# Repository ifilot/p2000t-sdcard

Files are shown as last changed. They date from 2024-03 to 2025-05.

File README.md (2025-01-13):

# P2000T SD-CARD cartridge







## Table of contents

* [Purpose](#purpose)
* [Downloads](#downloads)
* [How it functions](#how-it-functions)
* [Images](#images)
* [Commands](#commands)
* [Compilation instructions](#compilation-instructions)
* [Repository contents](#repository-contents)
* [Building the hardware](#building-the-hardware)
* [Ordering a cartridge](#ordering-a-cartridge)
* [Internal SD-card board](#internal-sd-card-board)
* [Formatting SD-card](#formatting-sd-card)
* [License](#license)

> [!TIP] 
> Have questions or comments about the **P2000T SD-card cartridge**? Join
> the conversation and chat with the developers on our [Discord
> server](https://discord.gg/YtzJTWYAxy).

## YouTube

Check out the YouTube video below for a detailed review of the SD-card cartridge.

YouTube (https://www.youtube.com/watch?v=OKvVlIvrEu0)

## Purpose

Perhaps the most elegant solution for loading CAS files into your P2000T or
making backups of your tapes is via a cartridge that hosts an SD-card slot. Even
the smallest SD-cards have enough capacity to store the complete P2000T tape
archive. Reading from such an SD-card is non-trivial and requires both a
hardware solution to interface with the I/O port of the P2000T as well as a
software solution to navigate through the files hosted on a FAT32 partition.
This repository contains the PCB for interfacing a P2000T with an SD-card and
the necessary software routines to grab .CAS files from said SD card and load
them into memory.

> [!TIP]
> **Documentation**
> * Detailed documentation included how-to procedures can be found [here](https://www.philips-p2000t.nl/cartridges/sdcard-cartridge.html#sdcard-cartridge)
> * There is also a [manual in Dutch](https://github.com/ifilot/P2000T-SD-kaart-handleiding) Dutch flag available.

## Downloads 

Read the section ["How it functions"](#how-it-functions) to understand what each
download file does.

> [!WARNING] 
> The files shown here cater specifically to PCB version 6 or later
> where the SD-card listens to I/O port 0x4X. Earlier version of the PCB are no
> longer actively maintained.

* [BASICBOOTSTRAP.BIN](https://github.com/ifilot/p2000t-sdcard/releases/latest/download/BASICBOOTSTRAP.BIN)
* [FLASHER.BIN](https://github.com/ifilot/p2000t-sdcard/releases/latest/download/FLASHER.BIN)
* [LAUNCHER.BIN](https://github.com/ifilot/p2000t-sdcard/releases/latest/download/LAUNCHER.BIN)

> [!TIP]
> * Precompiled SD-card images, including flashing instructions, can be found [here](https://github.com/ifilot/p2000t-sdcard-image)
> * A list of PRG programs, specifically designed to operate with the SD-card cartridge, can be found [here](https://github.com/ifilot/p2000t-sdcard-cartridge-programs)

## How it functions

To interface with the SD-card, an SD-card slot is connected to the I/O port of
the P2000T. Interfacing with the SD-card proceeds via the SPI protocol which is
encoded in hardware (in contrast to bit-banging the protocol in software). From
the perspective of the P2000T, simple 1-byte instructions can be sent and
retrieved from the SD-card. By sending specific commands, data is sent or
retrieved from the SD-card.

While the SLOT2 cartridge (which hooks up to the I/O port of the P2000T) hosts
the circuitry to interface with the SD-card, a SLOT1 cartridge is required that
hosts the software. In order to run BASIC programs that are stored on the
SD-card as `.CAS` files, the regular BASIC environment **and** the required
routines to interface with the SD-card need to be present in memory. For this
reason, a modified version of the BASIC environment is used which upon boot will
load a launcher application from the ROM chip on the SLOT2 cartridge into main
memory. This launcher application allows the user to navigate the SD-card and
load BASIC programs into memory and run these. Detailed instructions on this
process are found [here](https://www.philips-p2000t.nl/cartridges/sdcard-cartridge.html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).

The launcher application needs to be placed on the ROM chip by means of a
flasher program. The flasher program is a different SLOT1 cartridge which can be
downloaded from the [download section](#downloads). The flasher program will
copy a `LAUNCHER.BIN` file from the root folder of the SD-card to the ROM chip
on the SLOT2 cartridge. This procedure is also used to update the launcher
application. Details on this process can be found [here](https://www.philips-p2000t.nl/cartridges/sdcard-cartridge.html#flashing-the-launcher-onto-the-rom-chip).

It is also possible to make copies of existing tapes to the SD-card. For this
purpose, a `CASDUMP.PRG` program is written. These special types of programs can
be loaded from the SD-card and executes via the launcher application. After
completion, one automatically returns to the launcher, allowing one to load one
of the freshly copied programs.

## Images

SLOT2 cartridge enclosure and populated PCB.
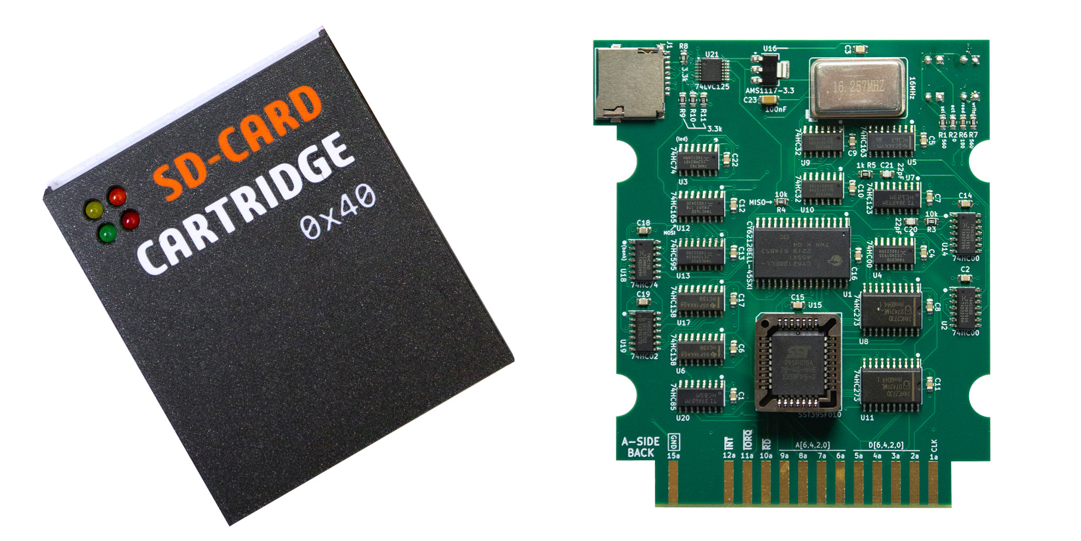
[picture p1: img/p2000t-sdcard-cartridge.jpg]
Image of cartridge and PCB


Screenshots of navigation and execution of .CAS files.
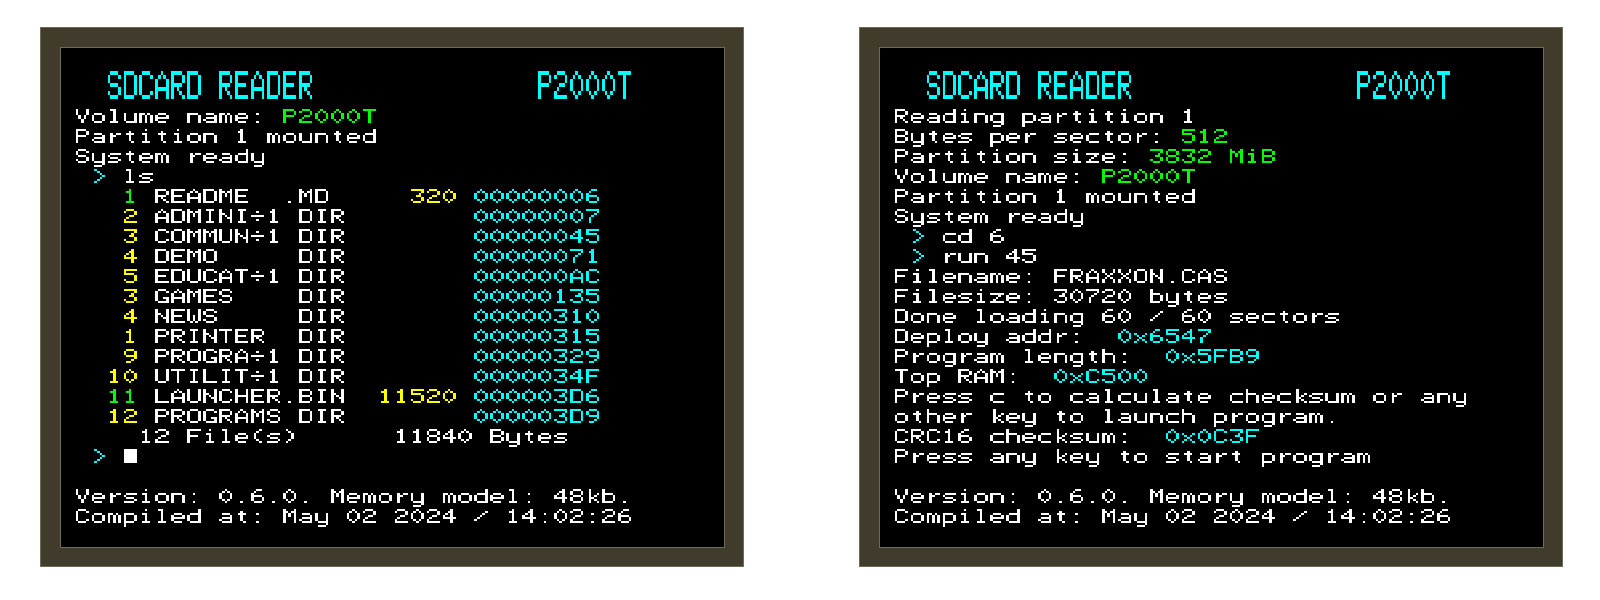
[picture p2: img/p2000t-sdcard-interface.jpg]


## Commands

Upon booting into the LAUNCHER application, the user interfaces with the SD-card
using a set of short commands. Below, the list of commands is provided

| **Command** | **Description** |
| --- | ---|
| `ls` | List contents of current folder |
| `lscas` | List contents of current folder, listing contents of CAS files |
| `cd <number>` | Change directory |
| `run <number>` | Run .CAS file |
| `hexdump <number>`  | Performs a 120-byte hexdump of a file |
| `fileinfo <number>` | Provides location details of a file |
| `ledtest` | Performs a quick test on the read/write LEDs |
| `stack` | Show current position of the stack pointer |
| `dump<XXXX>` | Perform a 120-byte hexdump of main memory starting at `0xXXXX` |
| `romdump<XXXX>` | Perform a 120-byte hexdump of cartridge ROM starting at `0xXXXX`  |
| `ramdump<XXXX>` | Perform a 120-byte hexdump of cartridge RAM starting at `0xXXXX`  |

Note that `<number>` needs to replaced with the specific number of a file. Users
who are familiar with command line interfaces are probably used to specifying
filenames rather than numbers. This reason this approach was chosen is mainly
because it is simpler to program and furthermore a bit quicker to type.

## Compilation instructions

Compilation is done using the [z88dk Docker](https://hub.docker.com/r/z88dk/z88dk)
by means of `compile.sh`. To compile the launcher, run

```bash
cd src
./compile launcher
```

and for the flasher utility

```bash
cd src
./compile flasher
```

## Repository contents

* [Cartridge cases](cases/)
* [PCB layout files (KiCAD)](pcb/port2-sdcard-interface/)
* [Modified BASIC ROM source files](basicmod/)
* [Launcher and Flasher programs](src/)
* [Custom programs](programs/)

## Building the hardware

### Gerber files

To create your own SLOT2 cartridge, download the GERBER files from
[here](pcb/port2-sdcard-interface/GERBERS/), put them in a `.ZIP` file and send
them to your favorite PCB print farm. The author of this repository mainly uses
[JLCPCB](https://jlcpcb.com/), but plenty of alternatives are available. The
SLOT2 PCB has four layers. It is recommended to apply an ENIG (gold) coating and
chamfer the edge connector for facile insertion into the P2000T. After ordering,
one needs to either hand-solder the components (which can be tricky for the SMD
chips) or alternatively make use of an assembly service by which the PCB print
farm will solder these components for you.

### PCB assembly service

The folder [pcb/port2-sdcard-interface](pcb/port2-sdcard-interface) contains
`port2-sdcard-interface_bom_bot.csv` and `port2-sdcard-interface-bottom-pos.csv`
which can be used for the JLCPCB assembly service. An example of the part
placement can be found in the image below. At the time of writing, two
components were unavailable, being the memory chip `62128` and a 0 ohm resistor,
which is the reason that these two parts are missing. Note that all through-hole
parts, e.g. LEDs, oscillator and PLCC32 socket, have to be hand-soldered in.

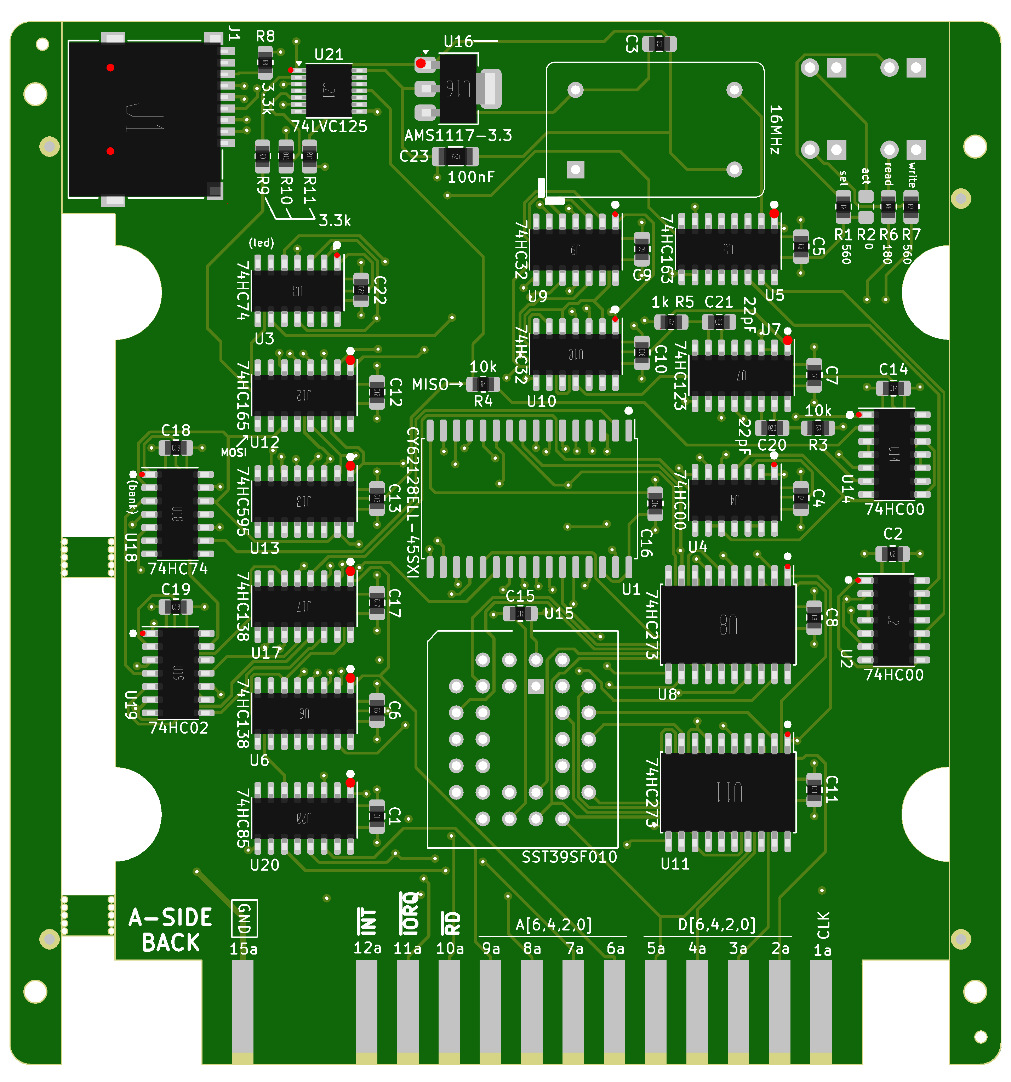
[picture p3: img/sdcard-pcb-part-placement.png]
img PCB assembly


### Ordering a cartridge

It is also possible to order a cartridge (typically there are always a few
of them in stock). If you are interested, feel free to contact the author of
this repository at `ivo at ivofilot dot nl` to discuss pricing and shipping.

## Internal SD-card board

This project also includes an [internal SD-card
board](pcb/internal-sdcard-interface/) designed to mount on top of the main
baseboard inside the P2000T. In addition to the SD-card reader functionality,
the board also provides 64 KiB of additional memory, making it an all-in-one
solution.

To install this board, you will need two custom brackets. You can find the
necessary bracket files [here](brackets).

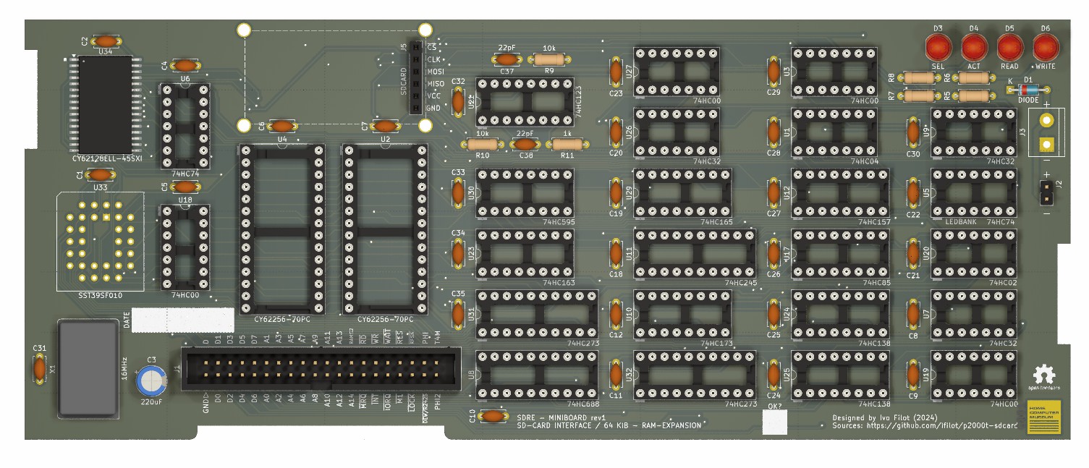
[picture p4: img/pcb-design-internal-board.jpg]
internal SD-card board


## Formatting SD-card

The way that the SD-card is formatted is critical. The SD-card needs be
formatted using a MBR/FAT32 partition. Often, directly formatting the SD-card
via Windows Explorer or similar works well, but sometimes a more rigorous
procedure is needed, which is explained below.

1. Type `WINDOWS + R` and run `CMD`.
2. Run `diskpart`.
3. Type `list disk` followed by `select disk <NR>` where `<NR>` corresponds to
   your SD-card.
4. Type `clean`. You get a response with `DiskPart succeeded in cleaning the
   disk.`.
5. Type `list volume`, followed by `select volume <ID>` where `<ID>` corresponds
   to your SD-card drive.
6. Type `convert mbr`. You should get the response `DiskPart successfully
   converted the selected disk to MBR format.`.
7. Type `create partition primary`. The response should be `DiskPart succeeded
   in creating the specified partition.`.
8. Finally, type `format fs=fat32 quick label="P2000T"`, after which the
   response is `DiskPart successfully formatted the volume.`.

Your SD-card should now be ready to work in the SD-cartridge. Of course, you
still need to copy files to it in order to load something of it.

## License

License facts

* All software is shared under the [GPL v3 license](https://www.gnu.org/licenses/gpl-3.0).
* All hardware (e.g. KiCAD files and .stl files) are shared under the [CERN-OHL-S license](https://ohwr.org/project/cernohl/-/wikis/uploads/819d71bea3458f71fba6cf4fb0f2de6b/cern_ohl_s_v2.txt).
* All documentation is shared under the [CC-BY-SA 4.0 license](https://creativecommons.org/licenses/by-sa/4.0/).

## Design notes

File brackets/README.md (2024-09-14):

# P2000T Mounting Brackets

This folder contains the STL files for two mounting brackets (see image below)
for installing the hybrid SD-card / memory expansion internal board.

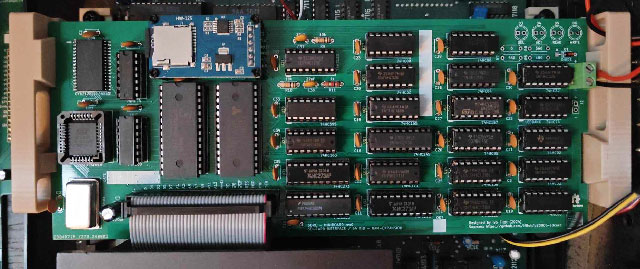
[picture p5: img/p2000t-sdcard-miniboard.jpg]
brackets on SD-card miniboard


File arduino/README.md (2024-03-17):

# Arduino SD-card interface

This folder contains a set of Arduino scripts to interface with an SD-card. These
scripts were used for prototyping the SD-card interface and are left here for
development purposes. These scripts are not used for the P2000T SD-card
cartridge.

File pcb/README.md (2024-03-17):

# PCB

This folder contains the PCBs for the [SLOT2 SD-card cartridge](port2-sdcard-interface) 
and also for a [SD-card interface prototype PCB](sdcard-prototype). 
The latter is only used for development purposes and can be ignored if one is 
solely interested in building a SLOT2 cartridge.

## Bill of materials

* 1 x CY62128ELL-45SXI
* 3 x 74HC00
* 2 x 74HC74
* 1 x 74HC163
* 2 x 74HC138
* 1 x 74HC123
* 2 x 74HC273
* 2 x 74HC32
* 1 x HC165
* 1 x HC595
* 1 x SST39SF010
* 1 x 74HC02
* 1 x 74HC85
* 1 x 16MHz crystal oscillator

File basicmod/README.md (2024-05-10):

# DEMO - IOLOADER

This example shows how via a small piece of injected code, another
piece of code can be loaded from the I/O port.

## Mechanism

To insert the custom code in the system RAM, two hijacks are made. The first
one is done in the startup procedure. Normally, at 0x1F71, a call is made to 
address 0x1056 which contains a jump to address 0x1F5A. This call is hijacked 
by changing the address pointer at 0x1057-0x1058 to 0x4EE0, which is an empty 
part of the BASIC rom. At this point, custom code is inserted which at its
end makes the required jump to 0x1F5A, from which the initiation procedure 
continues.

The small piece of code that is inserted at 0x4EE0 stores the value 0x55
at memory address 0x6150 (which is free to use). When this value is present,
another hijacked memory routine is activated. This routine is rather small
and resides at 0x4CE7. Here, a check is made whether memory address 0x6150
contains the value 0x55 and if so, a jump is made to 0x6151 where the bootloader
can place a custom pointer to any desired piece of code to be executed. When
desired, this custom piece of code can always return with a `jp 0029h` to
return to the BASIC execution (assuming no drastic changes are made to the
BASIC infrastructure).

## Output

* `BASICBOOTSTRAP.bin`: Modified BASIC cartridge

## Compilation instructions

Prepare the Docker compiler image

```bash
docker build . -t basicmod-compiler
```

Use the Docker image for the compilation

```bash
./compile
```

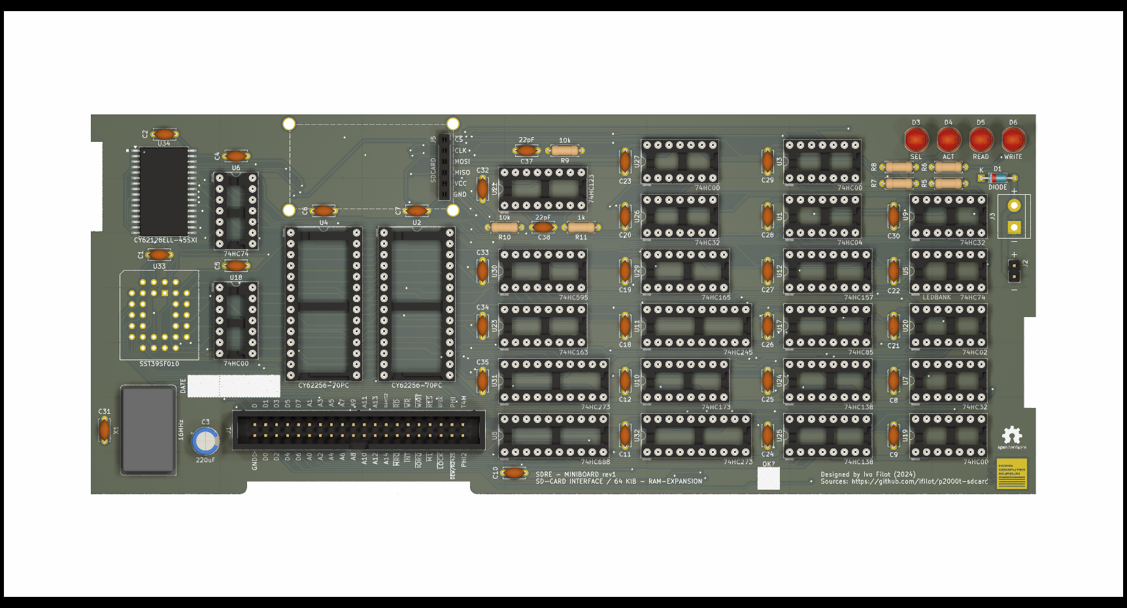
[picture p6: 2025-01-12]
img/pcb-design-internal-board.png

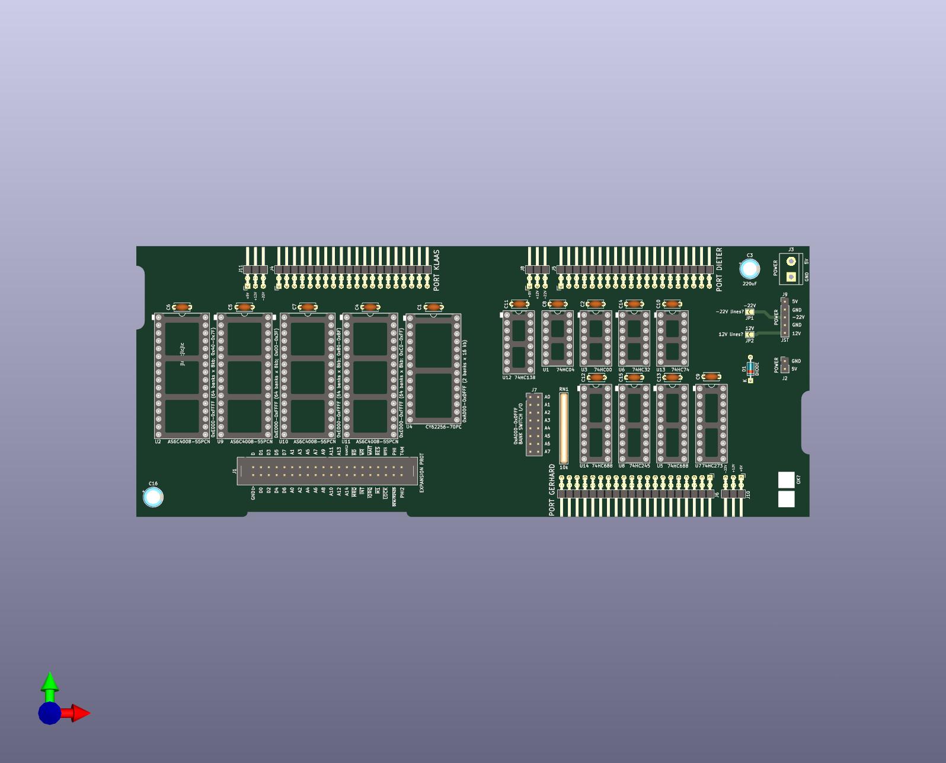
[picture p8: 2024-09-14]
pcb/internal-sdcard-interface/internal-sdcard-interface.jpg

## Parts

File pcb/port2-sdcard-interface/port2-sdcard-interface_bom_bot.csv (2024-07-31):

Designator | Comment | Footprint | LCSC Part #
U21 | 74LVC125 | Package_SO:TSSOP-14_4.4x5mm_P0.65mm | C6059
U16 | AMS1117-3.3 | Package_TO_SOT_SMD:SOT-223-3_TabPin2 | C5346136
R3,R4 | 10k | Resistor_SMD:R_0805_2012Metric_Pad1.20x1.40mm_HandSolder | C5159708
R5 | 1k | Resistor_SMD:R_0805_2012Metric_Pad1.20x1.40mm_HandSolder | C5123594
U1 | CY62128ELL-45SXI | Package_SO:SSOP-32_11.305x20.495mm_P1.27mm | C2840304
U2,U4,U14 | 74HC00 | Package_SO:SO-14_3.9x8.65mm_P1.27mm | C699445
C20,C21 | 22pF | Capacitor_SMD:C_0805_2012Metric_Pad1.18x1.45mm_HandSolder | C525286
R2 | 0 | Resistor_SMD:R_0805_2012Metric_Pad1.20x1.40mm_HandSolder | C431818
R6 | 180 | Resistor_SMD:R_0805_2012Metric_Pad1.20x1.40mm_HandSolder | C25270
R1,R7 | 560 | Resistor_SMD:R_0805_2012Metric_Pad1.20x1.40mm_HandSolder | C429158
R8,R9,R10,R11 | 3.3k | Resistor_SMD:R_0805_2012Metric_Pad1.20x1.40mm_HandSolder | C407459
J1 | Micro_SD_Card_Det1 | components:CONN9_MSD-1_CUD | C381082
U5 | 74HC163 | Package_SO:SOIC-16_3.9x9.9mm_P1.27mm | C338758
C23 | 100nF | Capacitor_SMD:C_1206_3216Metric_Pad1.33x1.80mm_HandSolder | C309030
U8,U11 | 74HC273 | Package_SO:SOIC-20W_7.5x12.8mm_P1.27mm | C131486
C1,C2,C3,C4,C5,C6,C7,C8,C9,C10,C11,C12,C13,C14,C15,C16,C17,C18,C19,C22 | 0.1uF | Capacitor_SMD:C_0805_2012Metric_Pad1.18x1.45mm_HandSolder | C126469
U3,U18 | 74HC74 | Package_SO:SO-14_3.9x8.65mm_P1.27mm | C27597
U20 | 74HC85 | Package_SO:SOIC-16_3.9x9.9mm_P1.27mm | C5953
U13 | 74HC595 | Package_SO:SOIC-16_3.9x9.9mm_P1.27mm | C5947
U9,U10 | 74HC32 | Package_SO:SO-14_3.9x8.65mm_P1.27mm | C5632
U12 | 74HC165 | Package_SO:SOIC-16_3.9x9.9mm_P1.27mm | C5613
U6,U17 | 74HC138 | Package_SO:SOIC-16_3.9x9.9mm_P1.27mm | C5602
U7 | 74HC123 | Package_SO:SOIC-16_3.9x9.9mm_P1.27mm | C5597
U19 | 74HC02 | Package_SO:SO-14_3.9x8.65mm_P1.27mm | C5588

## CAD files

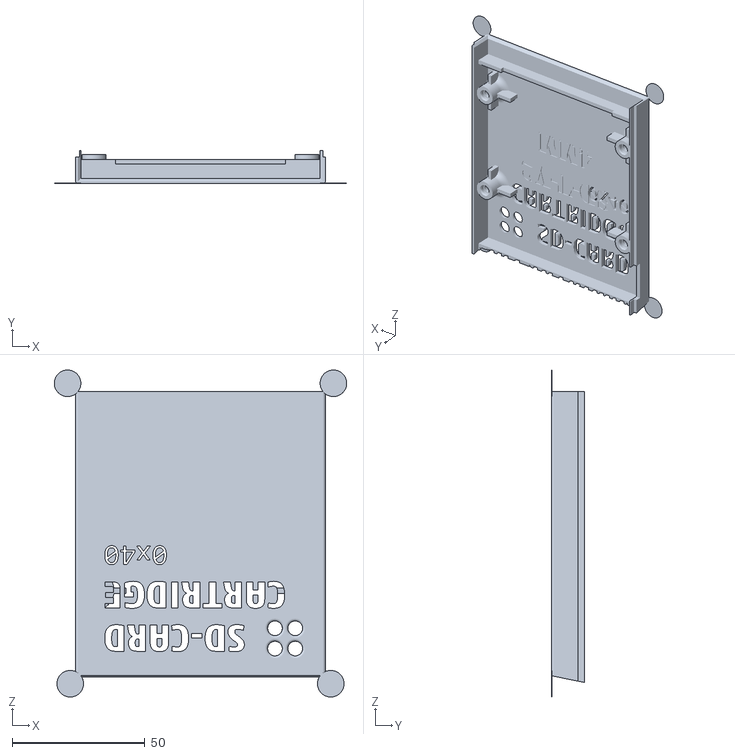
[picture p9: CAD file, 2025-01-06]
cases/multicolor/p2000t-sdcard-top-main.stl
110.0 x 12.5 x 123.0

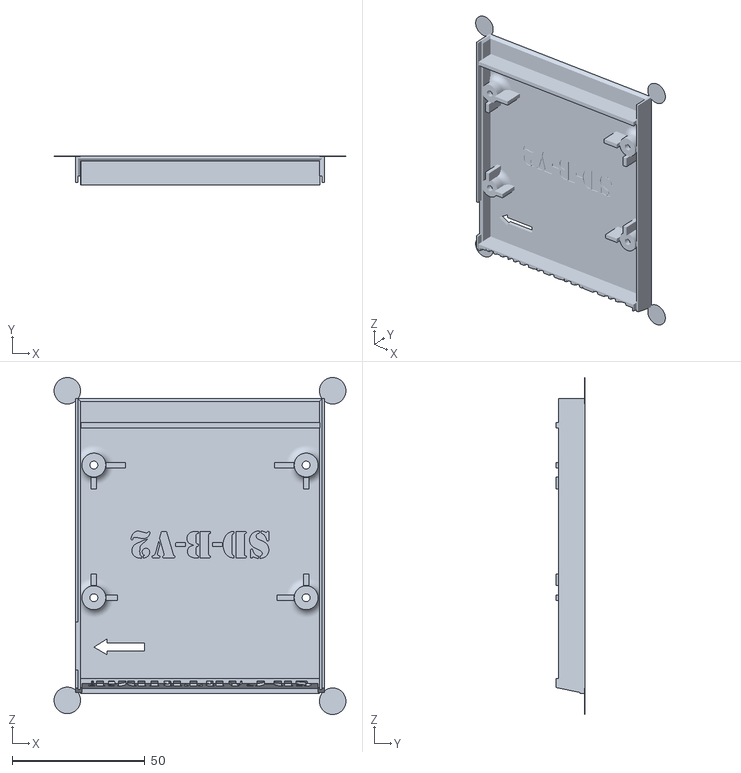
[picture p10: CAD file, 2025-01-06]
cases/multicolor/p2000t-sdcard-bottom-main.stl
110.0 x 11.0 x 127.0

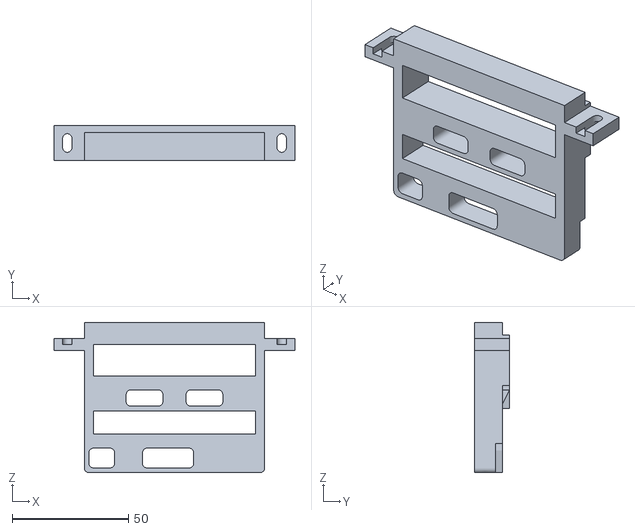
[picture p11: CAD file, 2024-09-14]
brackets/p2000t_SDRE_mounting_bracket_left.stl
103.5 x 15.0 x 64.5

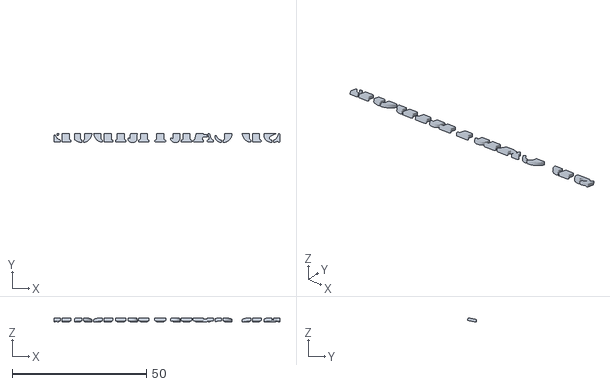
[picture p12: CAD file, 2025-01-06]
cases/multicolor/p2000t-sdcard-top-namelabel.stl
84.1 x 3.40 x 1.67

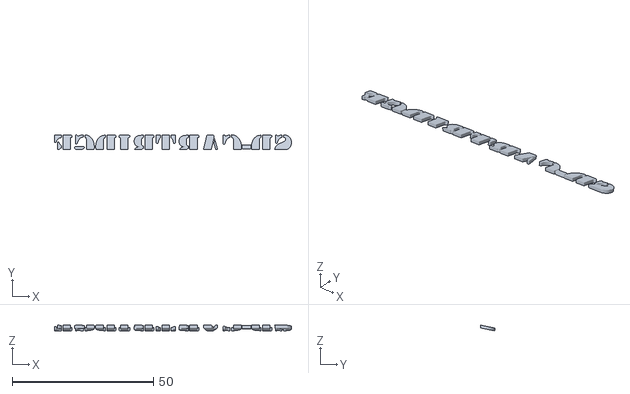
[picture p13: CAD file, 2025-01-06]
cases/multicolor/p2000t-sdcard-bottom-namelabel.stl
84.0 x 5.15 x 2.03

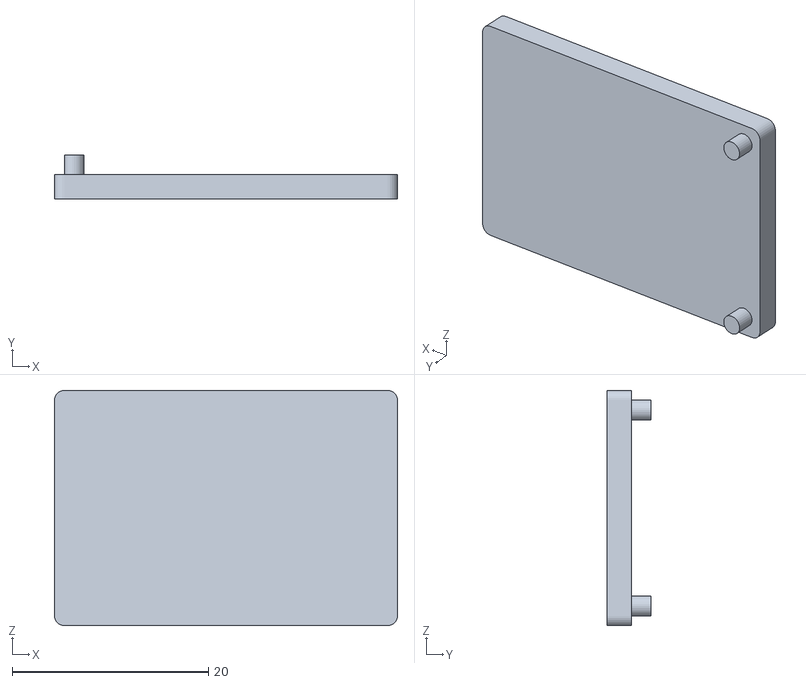
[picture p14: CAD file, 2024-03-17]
cases/single/sdcard-fixator-plate.stl
35.0 x 4.50 x 24.0

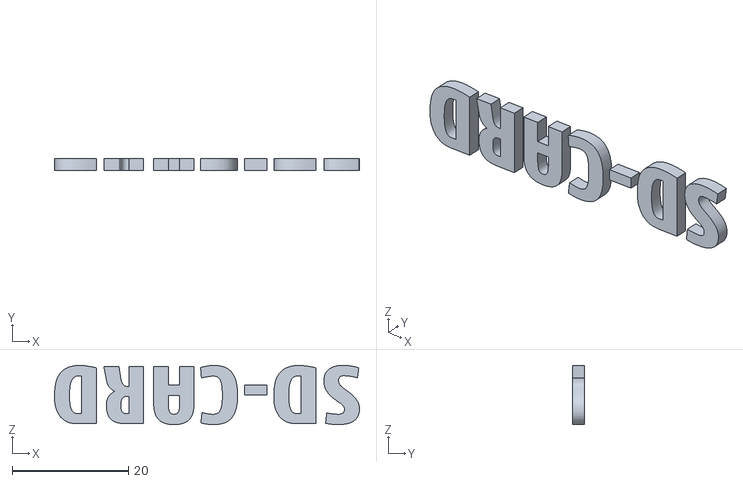
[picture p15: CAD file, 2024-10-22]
cases/multicolor/p2000t-sdcard-top-label01.stl
52.5 x 2.00 x 10.2

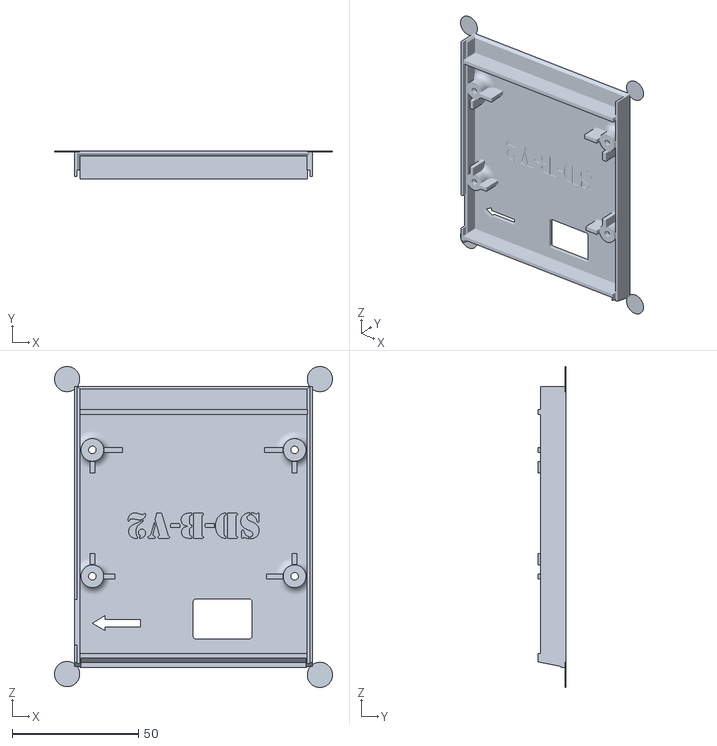
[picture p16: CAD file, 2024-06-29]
cases/multicolor/p2000t_multicartridge-bottom-osscillator-hole.stl
110.0 x 11.0 x 127.0

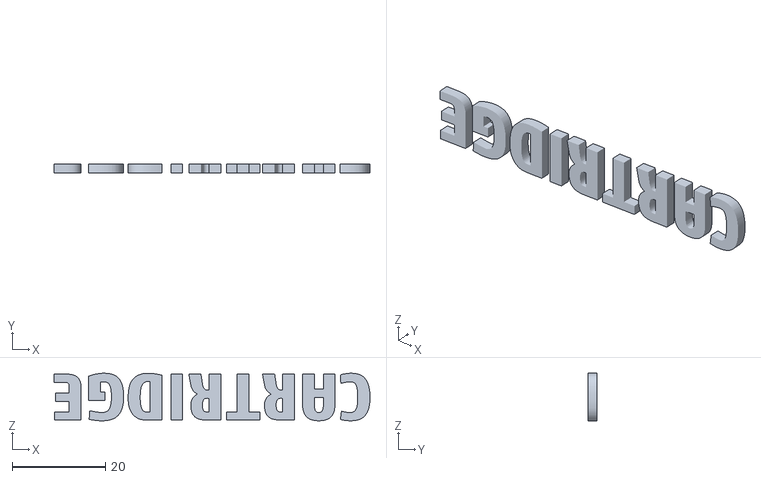
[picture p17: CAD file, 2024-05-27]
cases/multicolor/p2000t-sdcard-top-label02.stl
67.7 x 2.00 x 10.2

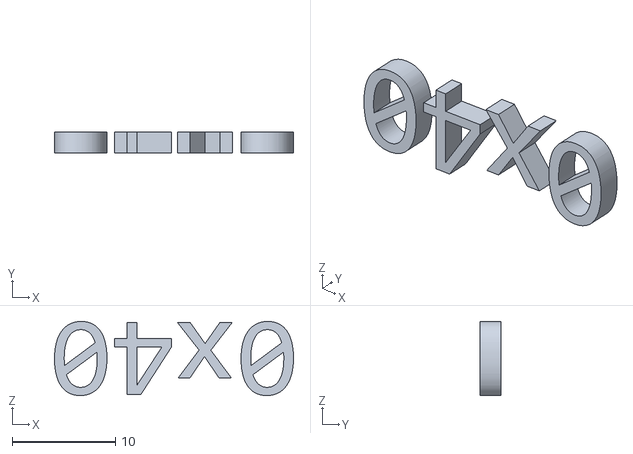
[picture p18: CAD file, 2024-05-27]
cases/multicolor/p2000t-sdcard-top-0x40-label.stl
23.2 x 2.00 x 7.19

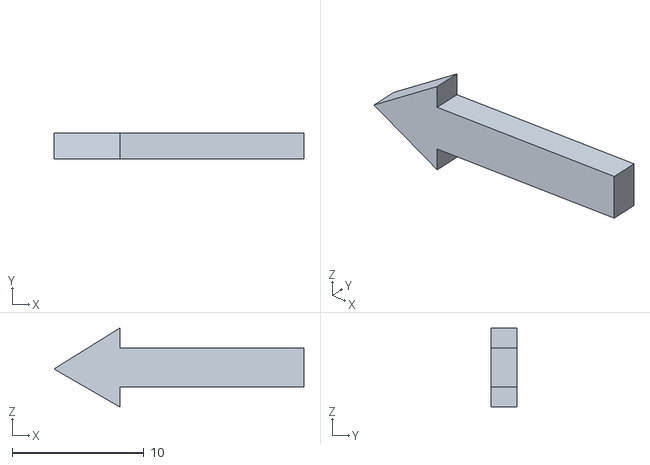
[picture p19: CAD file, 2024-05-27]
cases/multicolor/p2000t-sdcard-bottom-arrow.stl
19.0 x 2.00 x 6.00

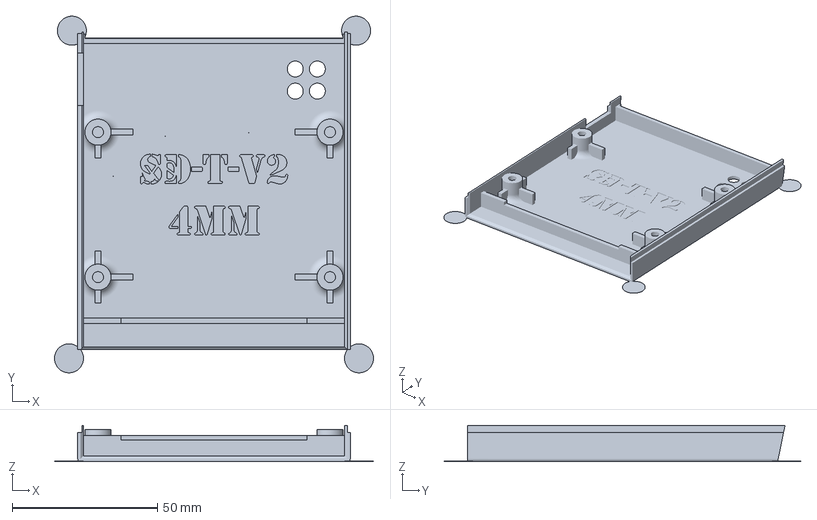
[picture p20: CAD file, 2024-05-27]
cases/multicolor/p2000t-sdcard-top.3mf
110.0 x 123.0 x 12.5 mm

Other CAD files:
cases/single/p2000t-sdcard-bottom.stl
brackets/p2000t_SDRE_mounting_bracket_right.stl
cases/single/p2000t-sdcard-top_4mm_inserts.stl
cases/single/p2000t-sdcard-top.stl
cases/multicolor/p2000t-sdcard-bottom.3mf

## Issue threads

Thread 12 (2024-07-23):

Good work and a little idea

emilen72, 2024-07-23:
Can you think to be possible to port this projet to use the pi pico rp2040, the purple clone with 16MB on board and make a multicart or a .cas loader from it? it would be very cheap :-) and easy to build (the hardware assembly of course)

it's already been done for atari 800 and othe console... some links that maybe you know...
https://forums.atariage.com/topic/351546-a8picocart-unocart-on-a-raspberry-pi-pico/
https://github.com/robinhedwards/A8PicoCart
https://github.com/aotta/PiCOLECO
https://github.com/aotta/SD-1000
https://github.com/aotta/PiRTOII

only a little idea :-)

best regards
Emiliano

ifilot, 2024-07-23:
This is indeed a nice suggestion and I have been pondering about this myself in the past. Two things held me back, the Raspberry Pi PICO has fewer pins than I would like and these pins operate at 3.3V, not 5.0V. Now there are a number of posts out there that suggest that the PICO is 5.0V tolerant with exception of the ADC pins, but so far I have not dared to put that to the test. All my projects involving the PICO use level-shifting.

I reckon porting this project to the PICO is certainly possible, essentially encoding what I have now put in hardware into software. It is something I might do in the future, but right now I have already enough projects on my hands and I would rather complete the ones I have now than starting new ones.

I do appreciate the list of links you have provided. If (when) I am going to adopt this endeavor, this will nicely kick-start the project.

Closed 2024-07-30.

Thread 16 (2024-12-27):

Ensure copper fill does not overlap with edge connector.

ifilot, 2024-12-27:
The manufacturing service observed that the copper fill around the edge connector sometimes results in exposed copper after the 30 deg chamfering step. Although most likely harmless, it is better to avoid this altogether.

Closed 2025-01-02.

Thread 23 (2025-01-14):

Sort filenames

ifilot, 2025-01-14:
In the current implementation, the files and directories are listed in the same order they are stored in that FAT32 system. Ideally, first directories are listed followed by files. With this functionality in place, it might also become possible to use commands like `run <filename>` rather than `run <number>`, but this is something we have to carefully evaluate as using the number-based system is a bit more efficient in terms of typing.

dionoid, 2025-06-06:
Sorting a long list of filenames will hurt the performance of the SD-cart cartridge, as all the files within a specific FAT32 folder need to be read and then sorted using the "power" of the old Z80 chip.

There are PC tools like [DriveSort](https://www.anerty.net/software/file/DriveSort/) (for Windows) and [FATSort](https://fatsort.sourceforge.io/) (for Linux/Mac) which both can sort FAT32 drives and allow you to choose if you want sort directories before files, or the other way around.

ifilot, 2025-06-07:
I can only agree with this. To provide some perspective: I have now implemented a FAT32 file sort routine for a 16 MHz 6502. There it is already noticeable suggesting that on a poor Z80 running at 2.5 MHz with much lower cycle efficiency, this will have a large negative impact. This will be a non-fix.

Closed 2025-06-07.

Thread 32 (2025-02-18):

viewing/running other files from a .cas file

fhil, 2025-02-18:
At the moment the 'lscas' command only shows the first file within a '.cas' file?
It would be really nice if 'lscas <num>' could be used to show all files within a '.cas' file.
And then use 'run <num>' to start an individual file.

I was trying to start the main program from the ancalagon.cas file. But that file is not the first file...

ifilot, 2025-02-18:
Thank you for raising this issue. Indeed, the firmware of the SD cartridge only lists the first "block" or "file" and the `run` command only starts the first file. If a CAS file contains multiple programs, only the first program or file can be accessed.

I need to align this with @dionoid how we wish to tackle this. I see a couple of options:
1. We instate the assumption that one CAS file should only contain one P2000T file. No multiple. CAS files that contain multiple P2000T files should then be broken up into separate ones. There is already software to do this.
2. We add a feature that allows the user to start the CAS file from any block (file) of interest. @dionoid has implemented a functionality to load a CAS file into memory and proceed to the BASIC prompt, but I am unsure whether this functionality allows one to load a file "in the middle" of a CAS file.

@dionoid: your view on this matter is appreciated here!

fhil, 2025-02-18:
I'd rather not breakup CAS files into multiple P2000T files.

Another way would be to allow basic to access the CAS file from memory and use rewind/cload/csave commands as if there is a tape present. If i'm correct, there are hooks inside the BASIC rom that might allow bending some of these functions.

dionoid, 2025-02-18:
> there are hooks inside the BASIC rom that might allow bending some of these functions.

True, but that would require the the custom code (which reads from SLOT2 memory instead of cassette) to be injected into the Basic ROM, which is quite a challenge size-wise. And some people probably want to keep the normal cload/csave features after loading a .cas file from SD-card, so they can e.g. save a program to cassette.

fhil, 2025-02-18:
If you can load the first file and also determine the size using the headers then you also know were the next file starts.
Each file is always one or more times a header(256 bytes)/block(1024 bytes) combo,
And then start to determine a size again to skip to the next file if needed.

fhil, 2025-02-18:
> > there are hooks inside the BASIC rom that might allow bending some of these functions.
>
> True, but that would require the the custom code (which reads from SLOT2 memory instead of cassette) to be injected into the Basic ROM, which is quite a challenge size-wise. And some people probably want to keep the normal cload/csave features after loading a .cas file from SD-card, so they can e.g. save a program to cassette.

It would be really cool if you could have an option for this to work on such a 'virtual' cassette.

ifilot, 2025-02-18:
> If you can load the first file and also determine the size using the headers then you also know were the next file starts.
> Each file is always one or more times a header(256 bytes)/block(1024 bytes) combo,
> And then start to determine a size again to skip to the next file if needed.

This is basically how the SD-cartridge works, yet there is no built-in functionality to check whether a CAS file has multiple files (e.g. because it has multiple different filenames in the metadata blocks nor any functionality if a CAS file has multiple files inside it, to allow the user to select one. The biggest constraint right now, as also mentioned by @dionoid, is that we are extremely restricted in terms of ROM size. At this point, adding new functionality comes at the expense of removing other functions.

I understand that breaking up a CAS file might be undesirable, especially if the intention of the original author was to keep things together on one cassette, yet it would be an easy solution that does not compromise on the things we already put in.

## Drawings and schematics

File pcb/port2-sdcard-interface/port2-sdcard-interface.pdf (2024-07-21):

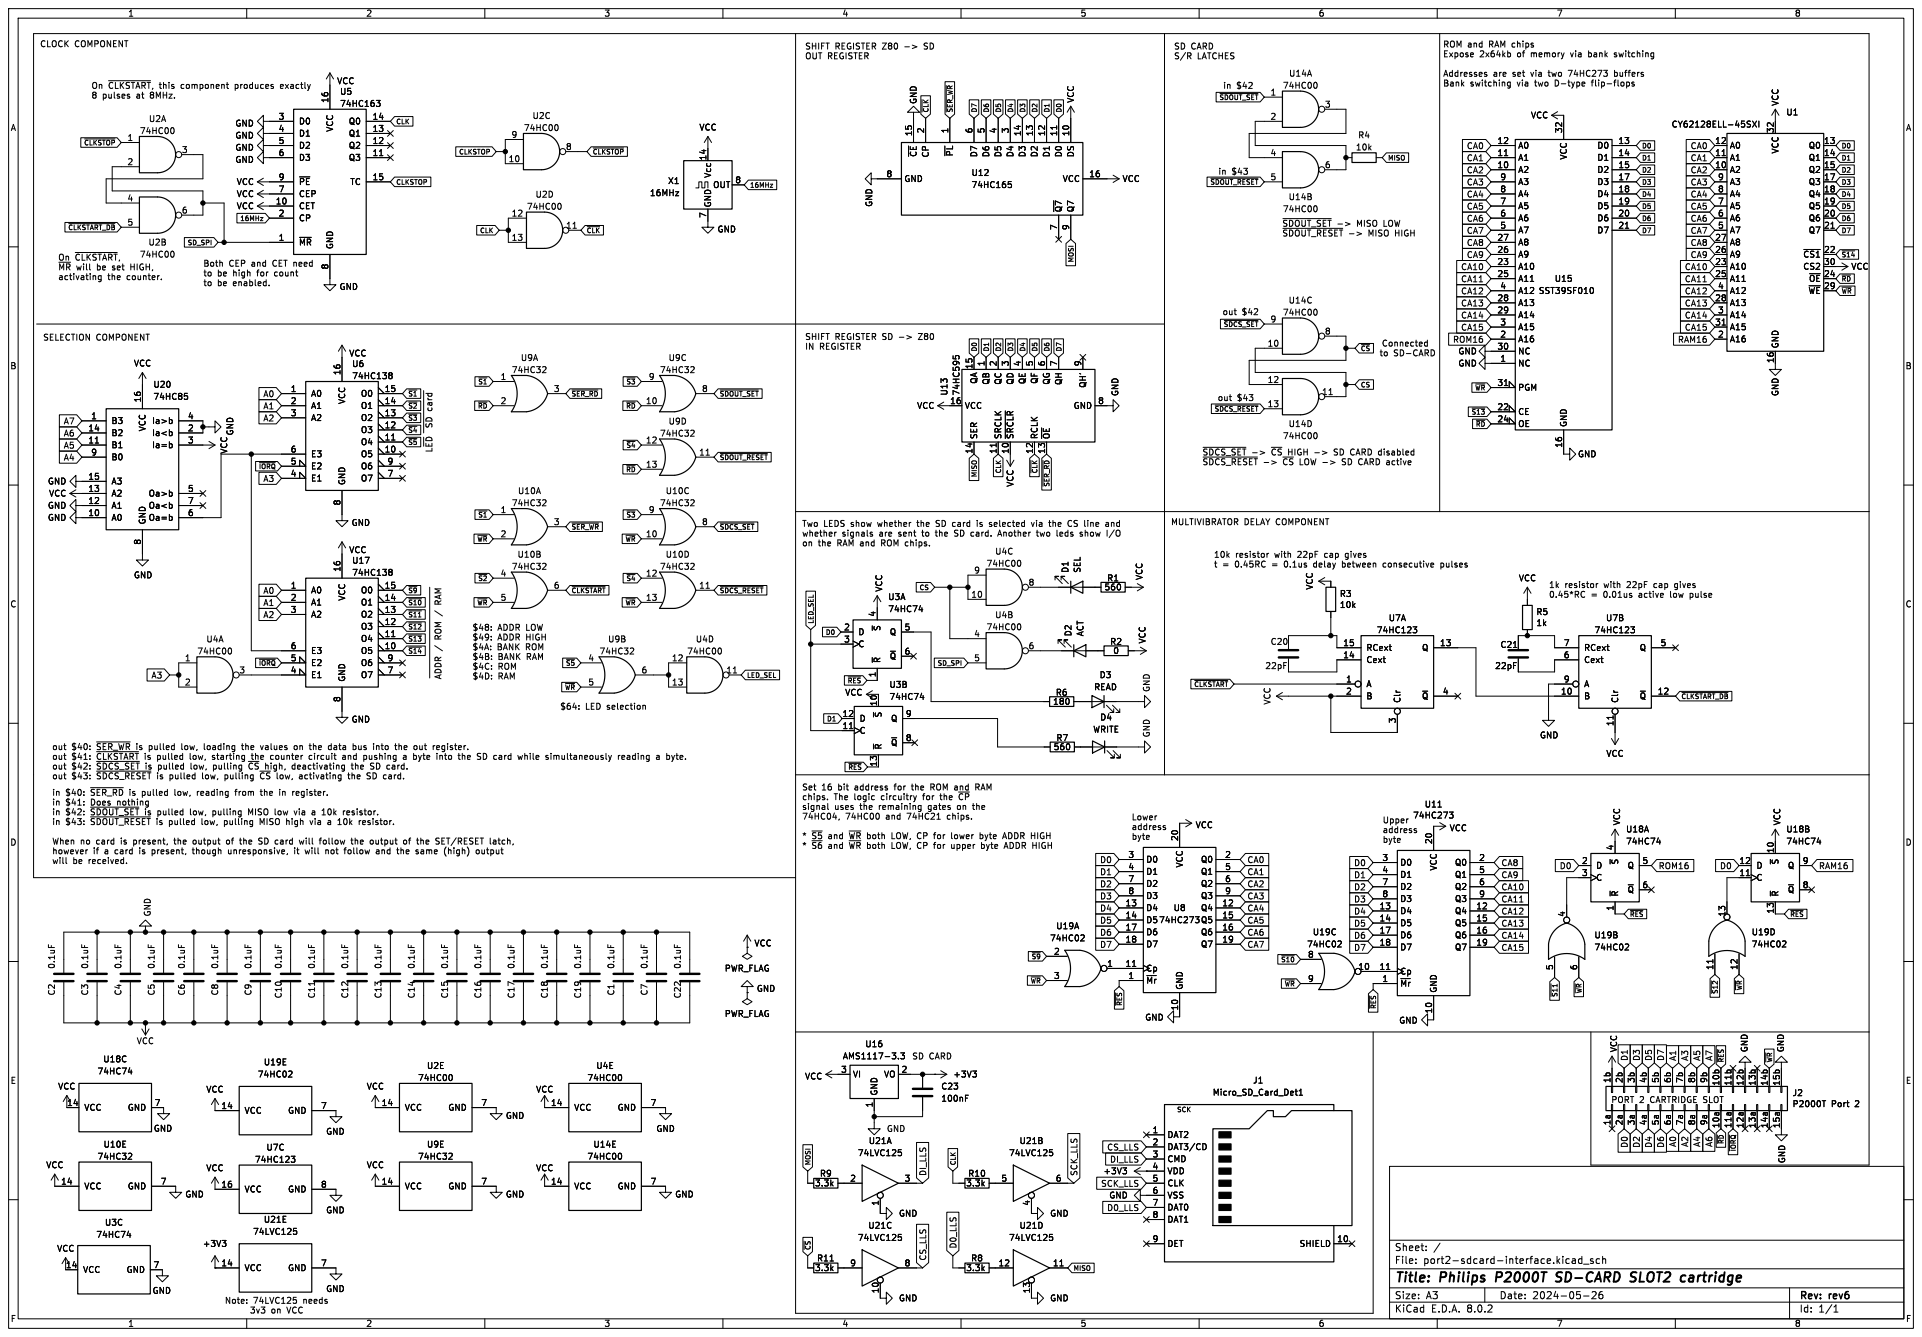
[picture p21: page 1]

ROM and RAM chips

in $43 Both CEP and CET need

to be enabled. On ~{CLKSTART},

to be high for count

1 ~{SRCLR} 10 SRCLK 11 RCLK 12 ~{OE} 13 SER 14 QA 15 VCC 16 QC

Set 16 bit address for the ROM and RAM
74HC04, 74HC00 and 74HC21 chips. * ~{S5}and ~{WR}both LOW, CP for lower byte ADDR HIGH

in $40: ~{SER_RD}is pulled low, reading from the in register.
in $41: Does nothing

* ~{S6}and ~{WR}both LOW, CP for upper byte ADDR HIGH

Id: 1/1 Title: Philips P2000T SD-CARD SLOT2 cartridge

Note: 74LVC125 needs 3v3 on VCC

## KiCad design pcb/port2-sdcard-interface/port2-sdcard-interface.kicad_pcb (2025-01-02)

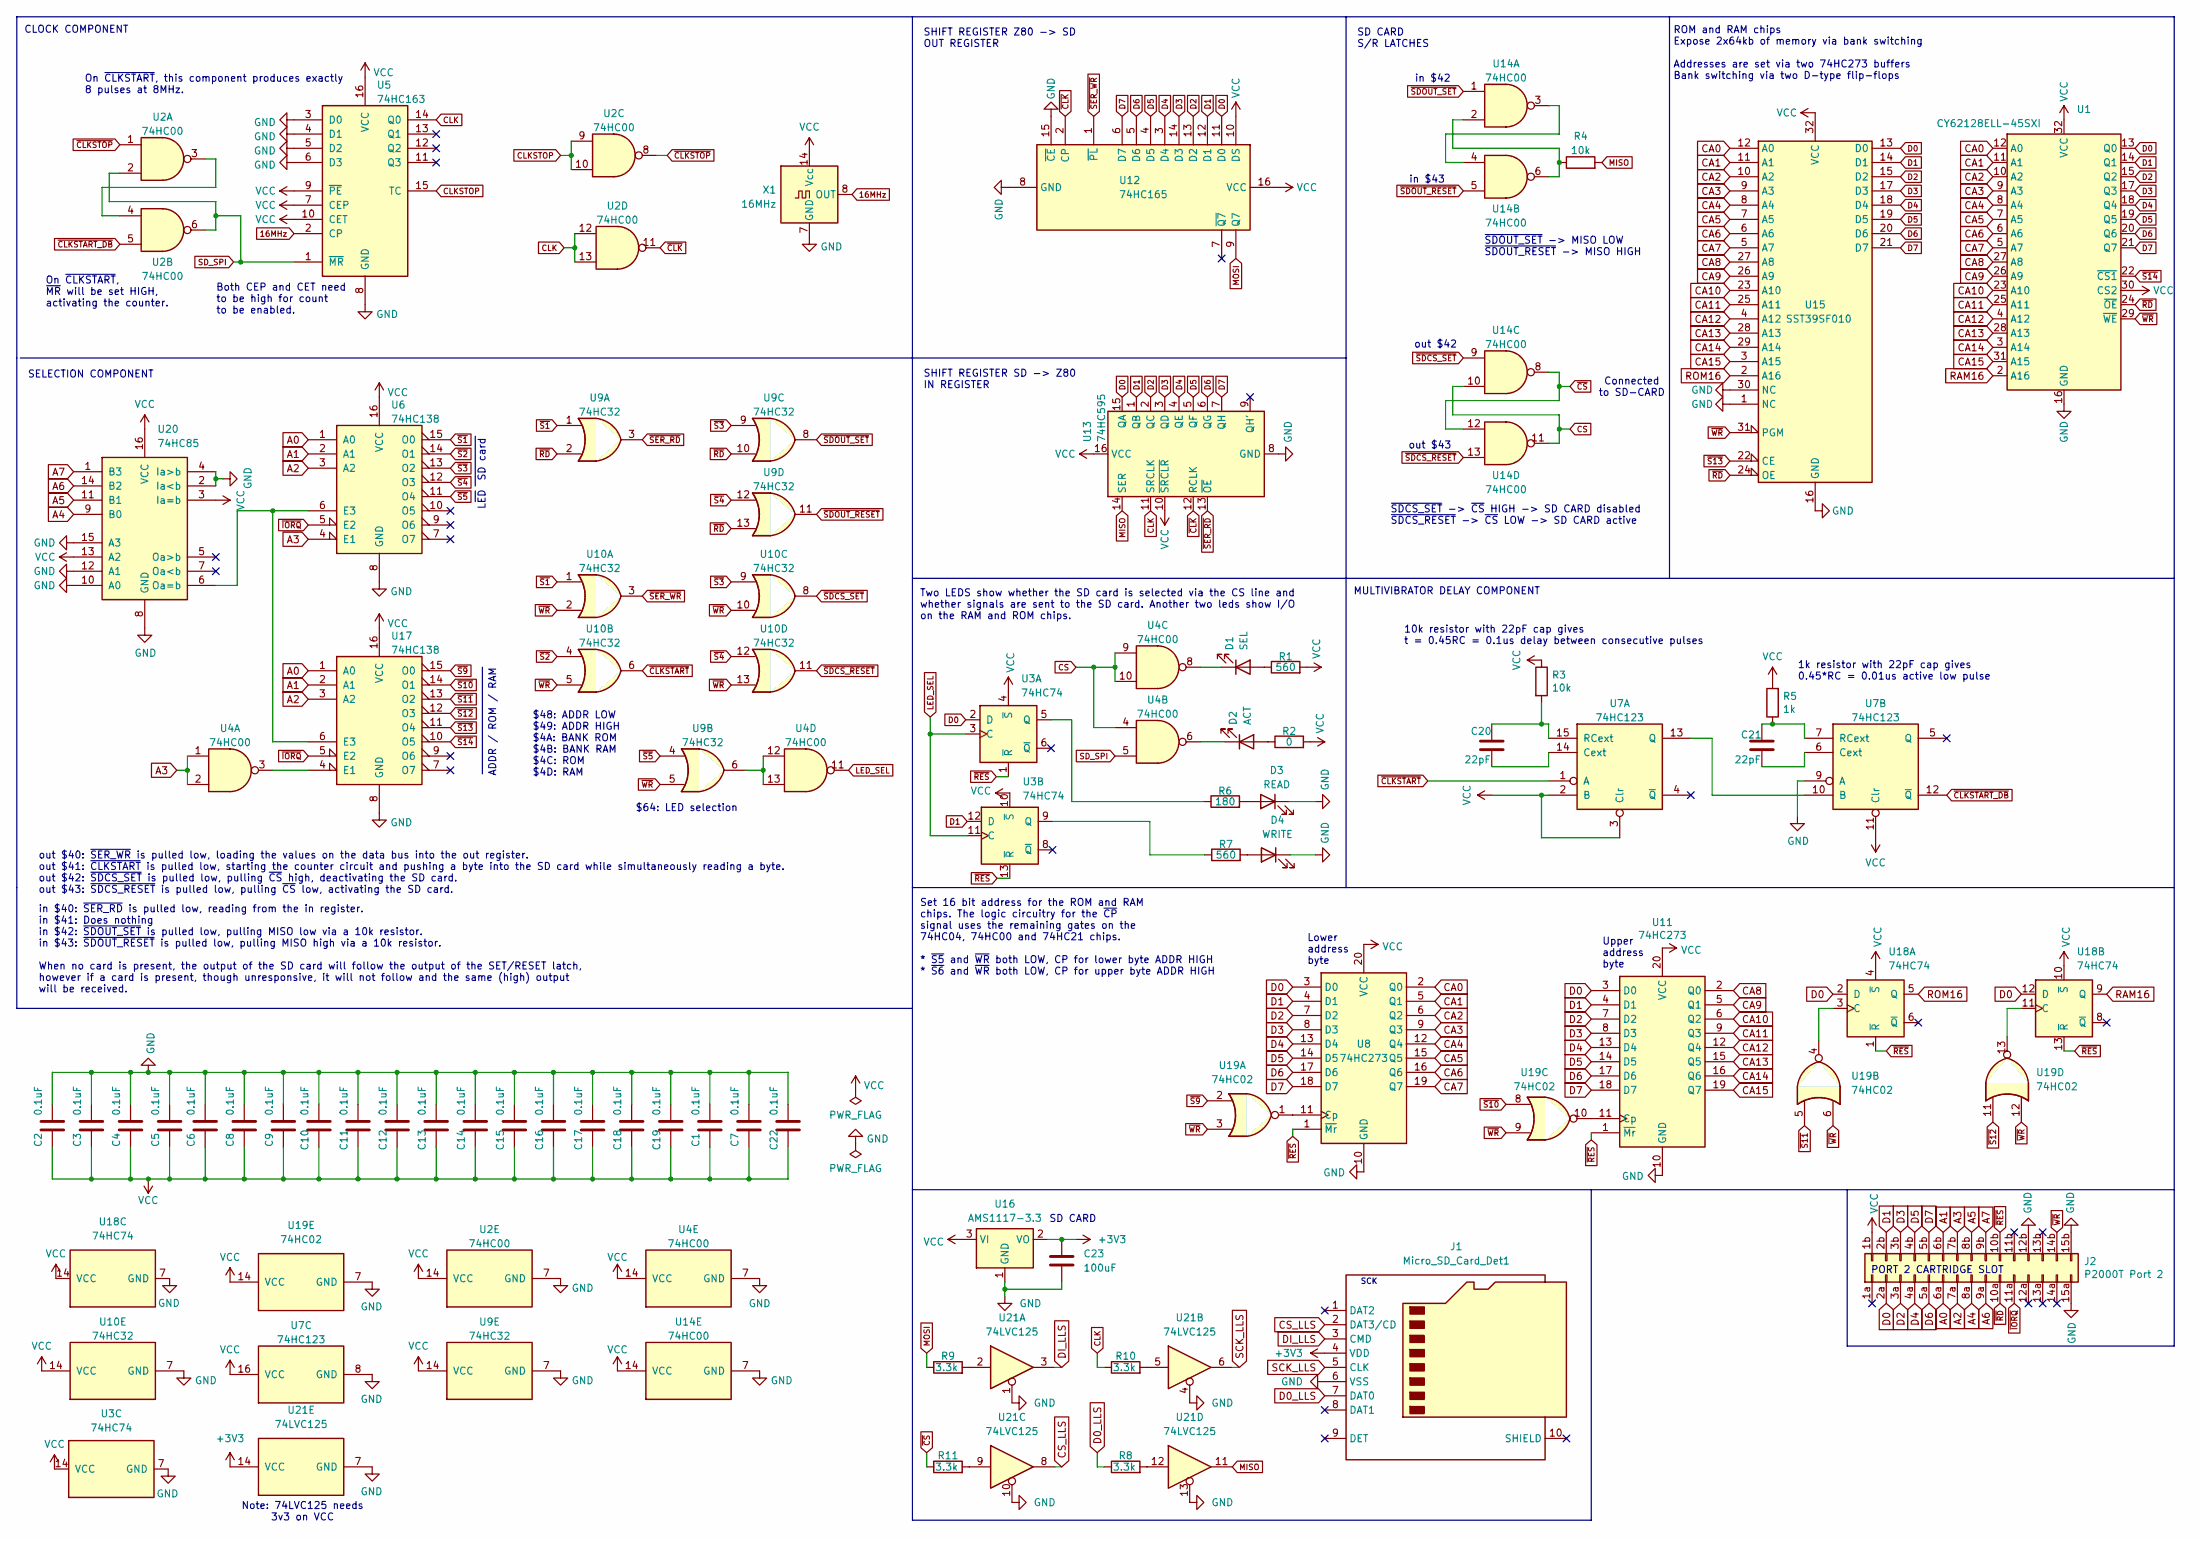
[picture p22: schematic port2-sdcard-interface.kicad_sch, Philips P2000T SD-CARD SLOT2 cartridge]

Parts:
C1, C2, C3, C4, C5, C6, C7, C8, C9, C10, C11, C12, C13, C14, C15, C16, C17, C18, C19, C22: 0.1uF; C_0805_2012Metric_Pad1.18x1.45mm_HandSolder; LCSC Part # C126469
C20, C21: 22pF; C_0805_2012Metric_Pad1.18x1.45mm_HandSolder; LCSC Part # C525286
C23: 100uF; C_1206_3216Metric_Pad1.33x1.80mm_HandSolder; LCSC Part # C309030
D1: SEL; LED_D5.0mm
D2: ACT; LED_D5.0mm
D3: READ; LED_D5.0mm
D4: WRITE; LED_D5.0mm
J1: Micro_SD_Card_Det1; CONN9_MSD-1_CUD; LCSC Part # C381082
J2: P2000T Port 2; p2000t_cartridge_edge
R1, R7: 560; R_0805_2012Metric_Pad1.20x1.40mm_HandSolder; LCSC Part # C429158
R2: 0; R_0805_2012Metric_Pad1.20x1.40mm_HandSolder; LCSC Part # C431818
R3, R4: 10k; R_0805_2012Metric_Pad1.20x1.40mm_HandSolder; LCSC Part # C5159708
R5: 1k; R_0805_2012Metric_Pad1.20x1.40mm_HandSolder; LCSC Part # C5123594
R6: 180; R_0805_2012Metric_Pad1.20x1.40mm_HandSolder; LCSC Part # C429158
R8, R9, R10, R11: 3.3k; R_0805_2012Metric_Pad1.20x1.40mm_HandSolder; LCSC Part # C407459
U1: CY62128ELL-45SXI; SSOP-32_11.305x20.495mm_P1.27mm; LCSC Part # C2840304
U2, U4, U14: 74HC00; SO-14_3.9x8.65mm_P1.27mm; LCSC Part # C699445
U3, U18: 74HC74; SO-14_3.9x8.65mm_P1.27mm; LCSC Part # C27597
U5: 74HC163; SOIC-16_3.9x9.9mm_P1.27mm; LCSC Part # C338758
U6, U17: 74HC138; SOIC-16_3.9x9.9mm_P1.27mm; LCSC Part # C5602
U7: 74HC123; SOIC-16_3.9x9.9mm_P1.27mm; LCSC Part # C5597
U8, U11: 74HC273; SOIC-20W_7.5x12.8mm_P1.27mm; LCSC Part # C131486
U9, U10: 74HC32; SO-14_3.9x8.65mm_P1.27mm; LCSC Part # C5632
U12: 74HC165; SOIC-16_3.9x9.9mm_P1.27mm; LCSC Part # C5613
U13: 74HC595; SOIC-16_3.9x9.9mm_P1.27mm; LCSC Part # C5947
U15: SST39SF010; PLCC-32_THT-Socket
U16: AMS1117-3.3; SOT-223-3_TabPin2; LCSC Part # C5346136
U19: 74HC02; SO-14_3.9x8.65mm_P1.27mm; LCSC Part # C5588
U20: 74HC85; SOIC-16_3.9x9.9mm_P1.27mm; LCSC Part # C5953
U21: 74LVC125; TSSOP-14_4.4x5mm_P0.65mm; LCSC Part # C7494906
X1: 16MHz; Oscillator_DIP-14

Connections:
16MHz: U5.2 (CP), X1.8 (OUT)
+3V3: C23.1, J1.4 (VDD), U16.2 (VO), U21.14 (VCC)
A0: J2.6a, U6.1 (A0), U17.1 (A0)
A1: J2.6b, U6.2 (A1), U17.2 (A1)
A2: J2.7a, U6.3 (A2), U17.3 (A2)
A3: J2.7b, U4.1, U4.2, U6.4 (E1)
A4: J2.8a, U20.9 (B0)
A5: J2.8b, U20.11 (B1)
A6: J2.9a, U20.14 (B2)
A7: J2.9b, U20.1 (B3)
CA0: U1.12 (A0), U8.2 (Q0), U15.12 (A0)
CA1: U1.11 (A1), U8.5 (Q1), U15.11 (A1)
CA2: U1.10 (A2), U8.6 (Q2), U15.10 (A2)
CA3: U1.9 (A3), U8.9 (Q3), U15.9 (A3)
CA4: U1.8 (A4), U8.12 (Q4), U15.8 (A4)
CA5: U1.7 (A5), U8.15 (Q5), U15.7 (A5)
CA6: U1.6 (A6), U8.16 (Q6), U15.6 (A6)
CA7: U1.5 (A7), U8.19 (Q7), U15.5 (A7)
CA8: U1.27 (A8), U11.2 (Q0), U15.27 (A8)
CA9: U1.26 (A9), U11.5 (Q1), U15.26 (A9)
CA10: U1.23 (A10), U11.6 (Q2), U15.23 (A10)
CA11: U1.25 (A11), U11.9 (Q3), U15.25 (A11)
CA12: U1.4 (A12), U11.12 (Q4), U15.4 (A12)
CA13: U1.28 (A13), U11.15 (Q5), U15.28 (A13)
CA14: U1.3 (A14), U11.16 (Q6), U15.29 (A14)
CA15: U1.31 (A15), U11.19 (Q7), U15.3 (A15)
CLK: R10.1, U2.12, U2.13, U5.14 (Q0), U13.11 (SRCLK)
CLKSTOP: U2.9, U2.10, U5.15 (TC)
CS: U4.4, U4.9, U4.10, U14.10, U14.11
CS_LLS: J1.2 (DAT3/CD), U21.8
D0: J2.2a, U1.13 (Q0), U3.2 (D), U8.3 (D0), U11.3 (D0), U12.11 (D0), U13.15 (QA), U15.13 (D0), U18.2 (D), U18.12 (D)
D0_LLS: J1.7 (DAT0), R8.1
D1: J2.2b, U1.14 (Q1), U3.12 (D), U8.4 (D1), U11.4 (D1), U12.12 (D1), U13.1 (QB), U15.14 (D1)
D2: J2.3a, U1.15 (Q2), U8.7 (D2), U11.7 (D2), U12.13 (D2), U13.2 (QC), U15.15 (D2)
D3: J2.3b, U1.17 (Q3), U8.8 (D3), U11.8 (D3), U12.14 (D3), U13.3 (QD), U15.17 (D3)
D4: J2.4a, U1.18 (Q4), U8.13 (D4), U11.13 (D4), U12.3 (D4), U13.4 (QE), U15.18 (D4)
D5: J2.4b, U1.19 (Q5), U8.14 (D5), U11.14 (D5), U12.4 (D5), U13.5 (QF), U15.19 (D5)
D6: J2.5a, U1.20 (Q6), U8.17 (D6), U11.17 (D6), U12.5 (D6), U13.6 (QG), U15.20 (D6)
D7: J2.5b, U1.21 (Q7), U8.18 (D7), U11.18 (D7), U12.6 (D7), U13.7 (QH), U15.21 (D7)
DI_LLS: J1.3 (CMD), U21.3
GND: C1.2, C2.2, C3.2, C4.2, C5.2, C6.2, C7.2, C8.2, C9.2, C10.2, C11.2, C12.2, C13.2, C14.2, C15.2, C16.2, C17.2, C18.2, C19.2, C22.2, C23.2, D3.1 (K), D4.1 (K), J1.6 (VSS), J2.12b, J2.15a, J2.15b, U1.16 (GND), U2.7 (GND), U3.7 (GND), U4.7 (GND), U5.3 (D0), U5.4 (D1), U5.5 (D2), U5.6 (D3), U5.8 (GND), U6.8 (GND), U7.8 (GND), U7.9 (A), U8.10 (GND), U9.7 (GND), U10.7 (GND), U11.10 (GND), U12.8 (GND), U12.15 (~CE), U13.8 (GND), U14.7 (GND), U15.1 (NC), U15.16 (GND), U15.30 (NC), U16.1 (GND), U17.8 (GND), U18.7 (GND), U19.7 (GND), U20.2 (Ia<b), U20.4 (Ia>b), U20.8 (GND), U20.10 (A0), U20.12 (A1), U20.15 (A3), U21.1, U21.4, U21.7 (GND), U21.10, U21.13, X1.7 (GND)
LED_SEL: U3.3 (C), U3.11 (C), U4.11
MISO: R4.2, U13.14 (SER), U21.11
MOSI: R9.1, U12.9 (Q7)
unnamed: D1.2 (A), R1.1
unnamed: D1.1 (K), U4.8
unnamed: D2.2 (A), R2.1
unnamed: D2.1 (K), U4.6
unnamed: D3.2 (A), R6.2
unnamed: D4.2 (A), R7.2
unnamed: R4.1, U14.2, U14.6
unnamed: R8.2, U21.12
unnamed: R9.2, U21.2
unnamed: R10.2, U21.5
unnamed: R11.2, U21.9
unnamed: U2.3, U2.4
unnamed: R6.1, U3.5 (Q)
unnamed: R7.1, U3.9 (Q)
unnamed: U4.12, U4.13, U9.6
unnamed: C20.1, U7.14 (Cext)
unnamed: U7.10 (B), U7.13 (Q)
unnamed: C20.2, R3.2, U7.15 (RCext)
unnamed: C21.1, U7.6 (Cext)
unnamed: C21.2, R5.1, U7.7 (RCext)
unnamed: U8.11 (Cp), U19.1
unnamed: U11.11 (Cp), U19.10
unnamed: U14.3, U14.4
unnamed: U4.3, U17.4 (E1)
unnamed: U6.6 (E3), U17.6 (E3), U20.6 (Oa=b)
unnamed: U18.3 (C), U19.4
unnamed: U18.11 (C), U19.13
RAM16: U1.2 (A16), U18.9 (Q)
ROM16: U15.2 (A16), U18.5 (Q)
SCK_LLS: J1.5 (CLK), U21.6
SD_SPI: U2.2, U2.6, U4.5, U5.1 (~MR)
VCC: C1.1, C2.1, C3.1, C4.1, C5.1, C6.1, C7.1, C8.1, C9.1, C10.1, C11.1, C12.1, C13.1, C14.1, C15.1, C16.1, C17.1, C18.1, C19.1, C22.1, J2.1b, R1.2, R2.2, R3.1, R5.2, U1.30 (CS2), U1.32 (VCC), U2.14 (VCC), U3.4 (~S), U3.10 (~S), U3.14 (VCC), U4.14 (VCC), U5.7 (CEP), U5.9 (~PE), U5.10 (CET), U5.16 (VCC), U6.16 (VCC), U7.2 (B), U7.3 (Clr), U7.11 (Clr), U7.16 (VCC), U8.20 (VCC), U9.14 (VCC), U10.14 (VCC), U11.20 (VCC), U12.10 (DS), U12.16 (VCC), U13.10 (~SRCLR), U13.16 (VCC), U14.14 (VCC), U15.32 (VCC), U16.3 (VI), U17.16 (VCC), U18.4 (~S), U18.10 (~S), U18.14 (VCC), U19.14 (VCC), U20.3 (Ia=b), U20.13 (A2), U20.16 (VCC), X1.14 (Vcc)
~CLKSTART_DB: U2.5, U7.12 (~Q)
~CLKSTART: U7.1 (A), U10.6
~CLKSTOP: U2.1, U2.8
~CLK: U2.11, U12.2 (CP), U13.12 (RCLK)
~CS: R11.1, U14.8, U14.12
~IORQ: J2.11a, U6.5 (E2), U17.5 (E2)
~RD: J2.10a, U1.24 (~OE), U9.2, U9.10, U9.13, U15.24 (OE)
~RES: J2.10b, U3.1 (~R), U3.13 (~R), U8.1 (~Mr), U11.1 (~Mr), U18.1 (~R), U18.13 (~R)
~S1: U6.15 (O0), U9.1, U10.1
~S2: U6.14 (O1), U10.4
~S3: U6.13 (O2), U9.9, U10.9
~S4: U6.12 (O3), U9.12, U10.12
~S5: U6.11 (O4), U9.4
~S9: U17.15 (O0), U19.2
~S10: U17.14 (O1), U19.8
~S11: U17.13 (O2), U19.5
~S12: U17.12 (O3), U19.11
~S13: U15.22 (CE), U17.11 (O4)
~S14: U1.22 (~CS1), U17.10 (O5)
~SDCS_RESET: U10.11, U14.13
~SDCS_SET: U10.8, U14.9
~SDOUT_RESET: U9.11, U14.5
~SDOUT_SET: U9.8, U14.1
~SER_RD: U9.3, U13.13 (~OE)
~SER_WR: U10.3, U12.1 (~PL)
~WR: J2.14b, U1.29 (~WE), U9.5, U10.2, U10.5, U10.10, U10.13, U15.31 (PGM), U19.3, U19.6, U19.9, U19.12

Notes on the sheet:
Note: 74LVC125 needs 3v3 on VCC
SD card
$64: LED selection
SHIFT REGISTER SD -> Z80 IN REGISTER
SD CARD S/R LATCHES
out $40: ~{SER_WR} is pulled low, loading the values on the data bus into the out register. out $41: ~{CLKSTART} is pulled low, starting the counter circuit and pushing a byte into the SD card while simultaneously reading a byte. out $42: ~{SDCS_SET} is pulled low, pulling ~{CS} high, deactivating 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
LED
On ~{CLKSTART}, this component produces exactly 8 pulses at 8MHz.
Set 16 bit address for the ROM and RAM chips. The logic circuitry for the ~{CP} signal uses the remaining gates on the 74HC04, 74HC00 and 74HC21 chips. * ~{S5} and ~{WR} both LOW, CP for lower byte ADDR HIGH * ~{S6} and ~{WR} both LOW, CP for upper byte ADDR HIGH
On ~{CLKSTART}, ~{MR} will be set HIGH, activating the counter.
Lower address byte
in $42
in $40: ~{SER_RD} is pulled low, reading from the in register. in $41: Does nothing in $42: ~{SDOUT_SET} is pulled low, pulling MISO low via a 10k resistor. in $43: ~{SDOUT_RESET} is pulled low, pulling MISO high via a 10k resistor. When no card is present, the output of the SD card will follow the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
Connected to SD-CARD
SD CARD
~{SDOUT_SET} -> MISO LOW ~{SDOUT_RESET} -> MISO HIGH
~{SDCS_SET} -> ~{CS} HIGH -> SD CARD disabled ~{SDCS_RESET} -> ~{CS} LOW -> SD CARD active
SELECTION COMPONENT
1k resistor with 22pF cap gives 0.45*RC = 0.01us active low pulse
10k resistor with 22pF cap gives t = 0.45RC = 0.1us delay between consecutive pulses
CLOCK COMPONENT
ADDR / ROM / RAM
in $43
Both CEP and CET need to be high for count to be enabled.
SCK
$48: ADDR LOW $49: ADDR HIGH $4A: BANK ROM $4B: BANK RAM $4C: ROM $4D: RAM
MULTIVIBRATOR DELAY COMPONENT
Upper address byte
PORT 2 CARTRIDGE SLOT
SHIFT REGISTER Z80 -> SD OUT REGISTER
out $42
out $43
Two LEDS show whether the SD card is selected via the CS line and whether signals are sent to the SD card. Another two leds show I/O on the RAM and ROM chips.
ROM and RAM chips Expose 2x64kb of memory via bank switching Addresses are set via two 74HC273 buffers Bank switching via two D-type flip-flops

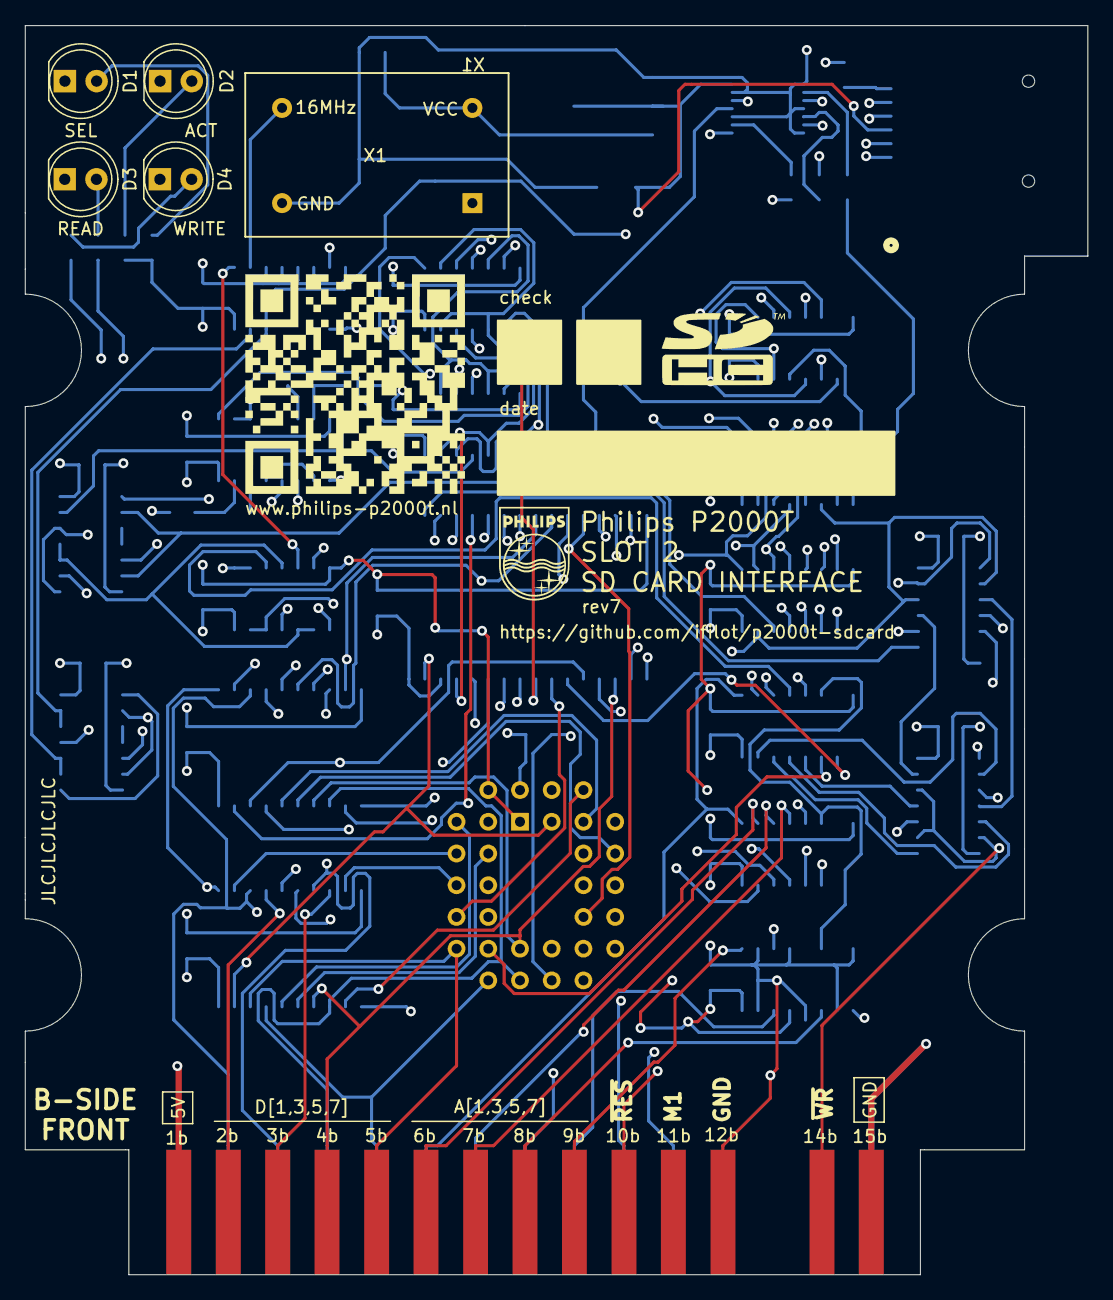
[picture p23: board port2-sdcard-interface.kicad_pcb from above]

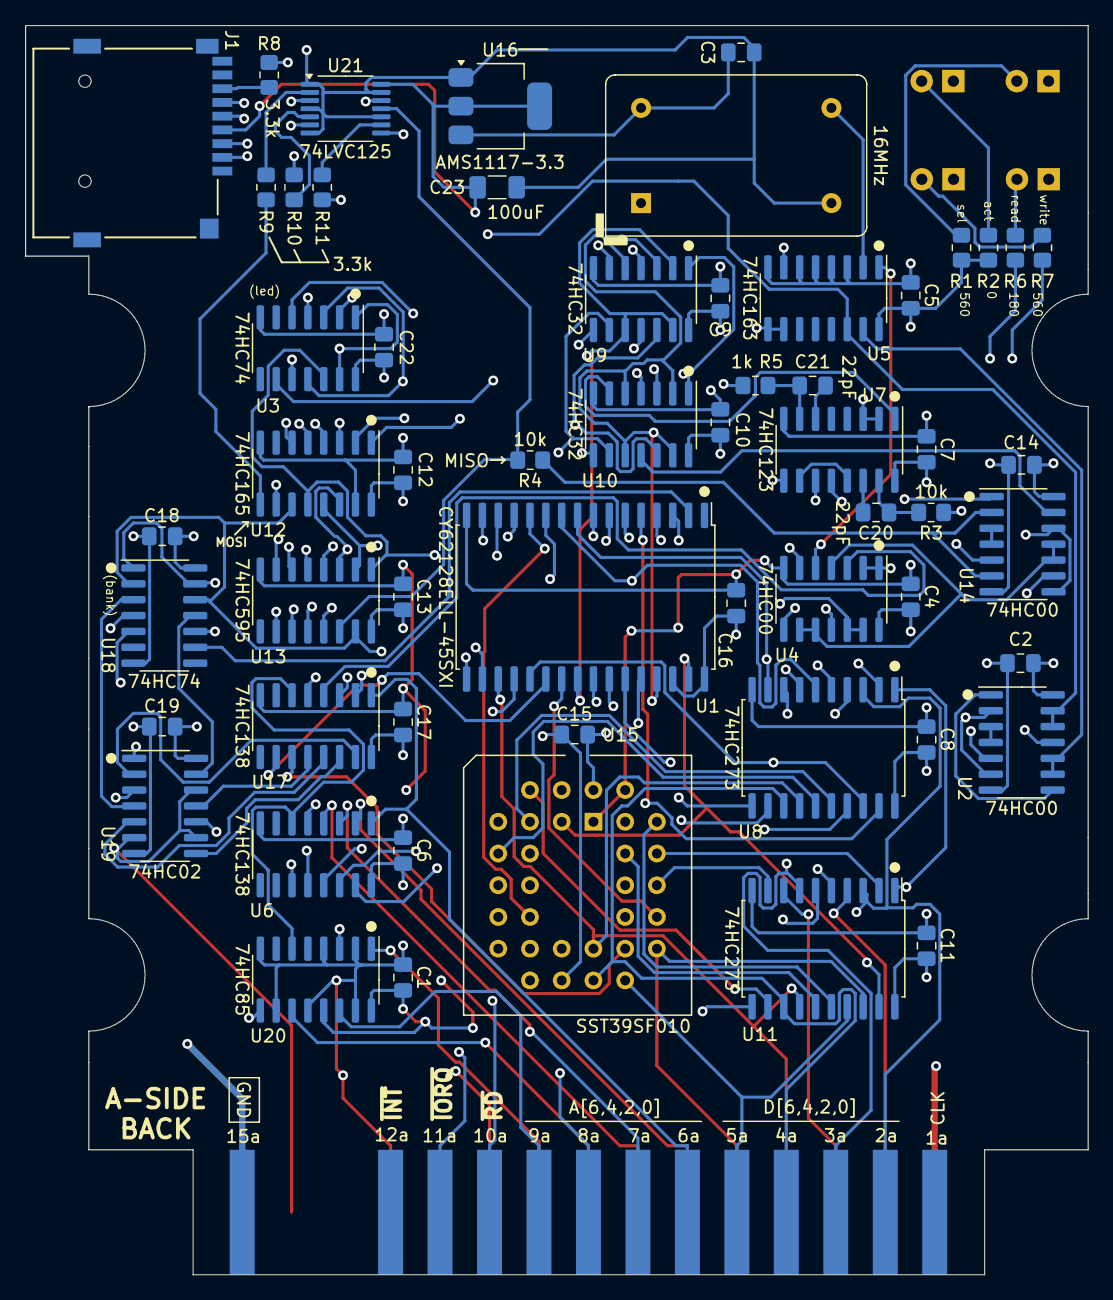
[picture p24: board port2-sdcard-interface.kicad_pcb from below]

Board: 4 copper layers, 85.1 x 100.0 mm, 65 parts (58 on the bottom side), 102 nets.

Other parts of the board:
G002: LOGO; qrcode
G003: LOGO; philips_logo
G004: LOGO; sdcard_logo

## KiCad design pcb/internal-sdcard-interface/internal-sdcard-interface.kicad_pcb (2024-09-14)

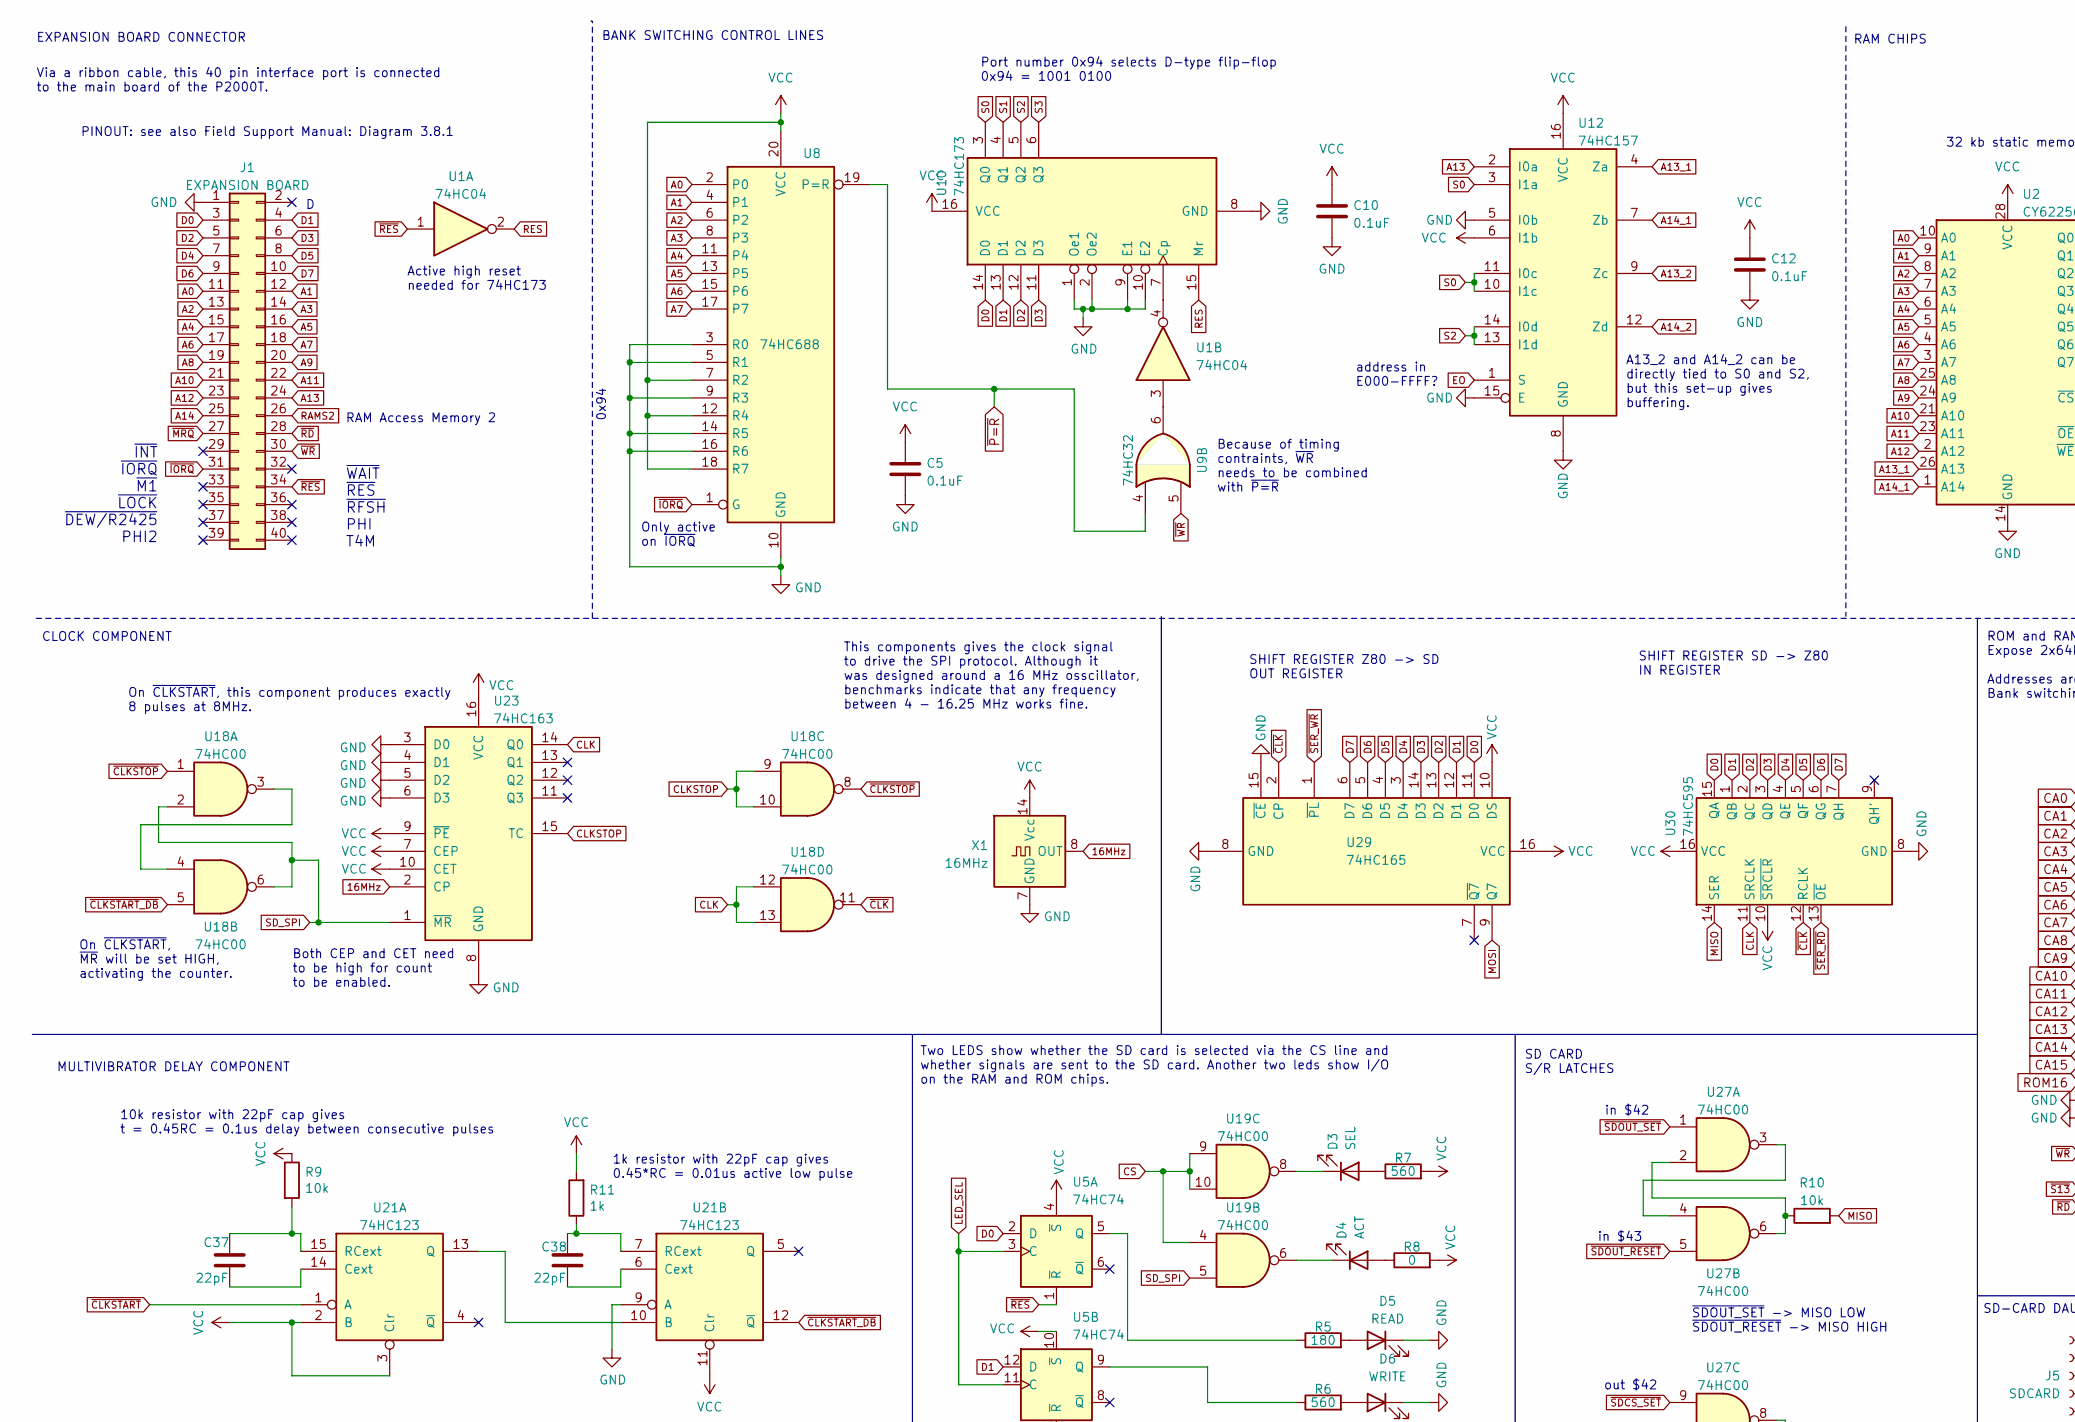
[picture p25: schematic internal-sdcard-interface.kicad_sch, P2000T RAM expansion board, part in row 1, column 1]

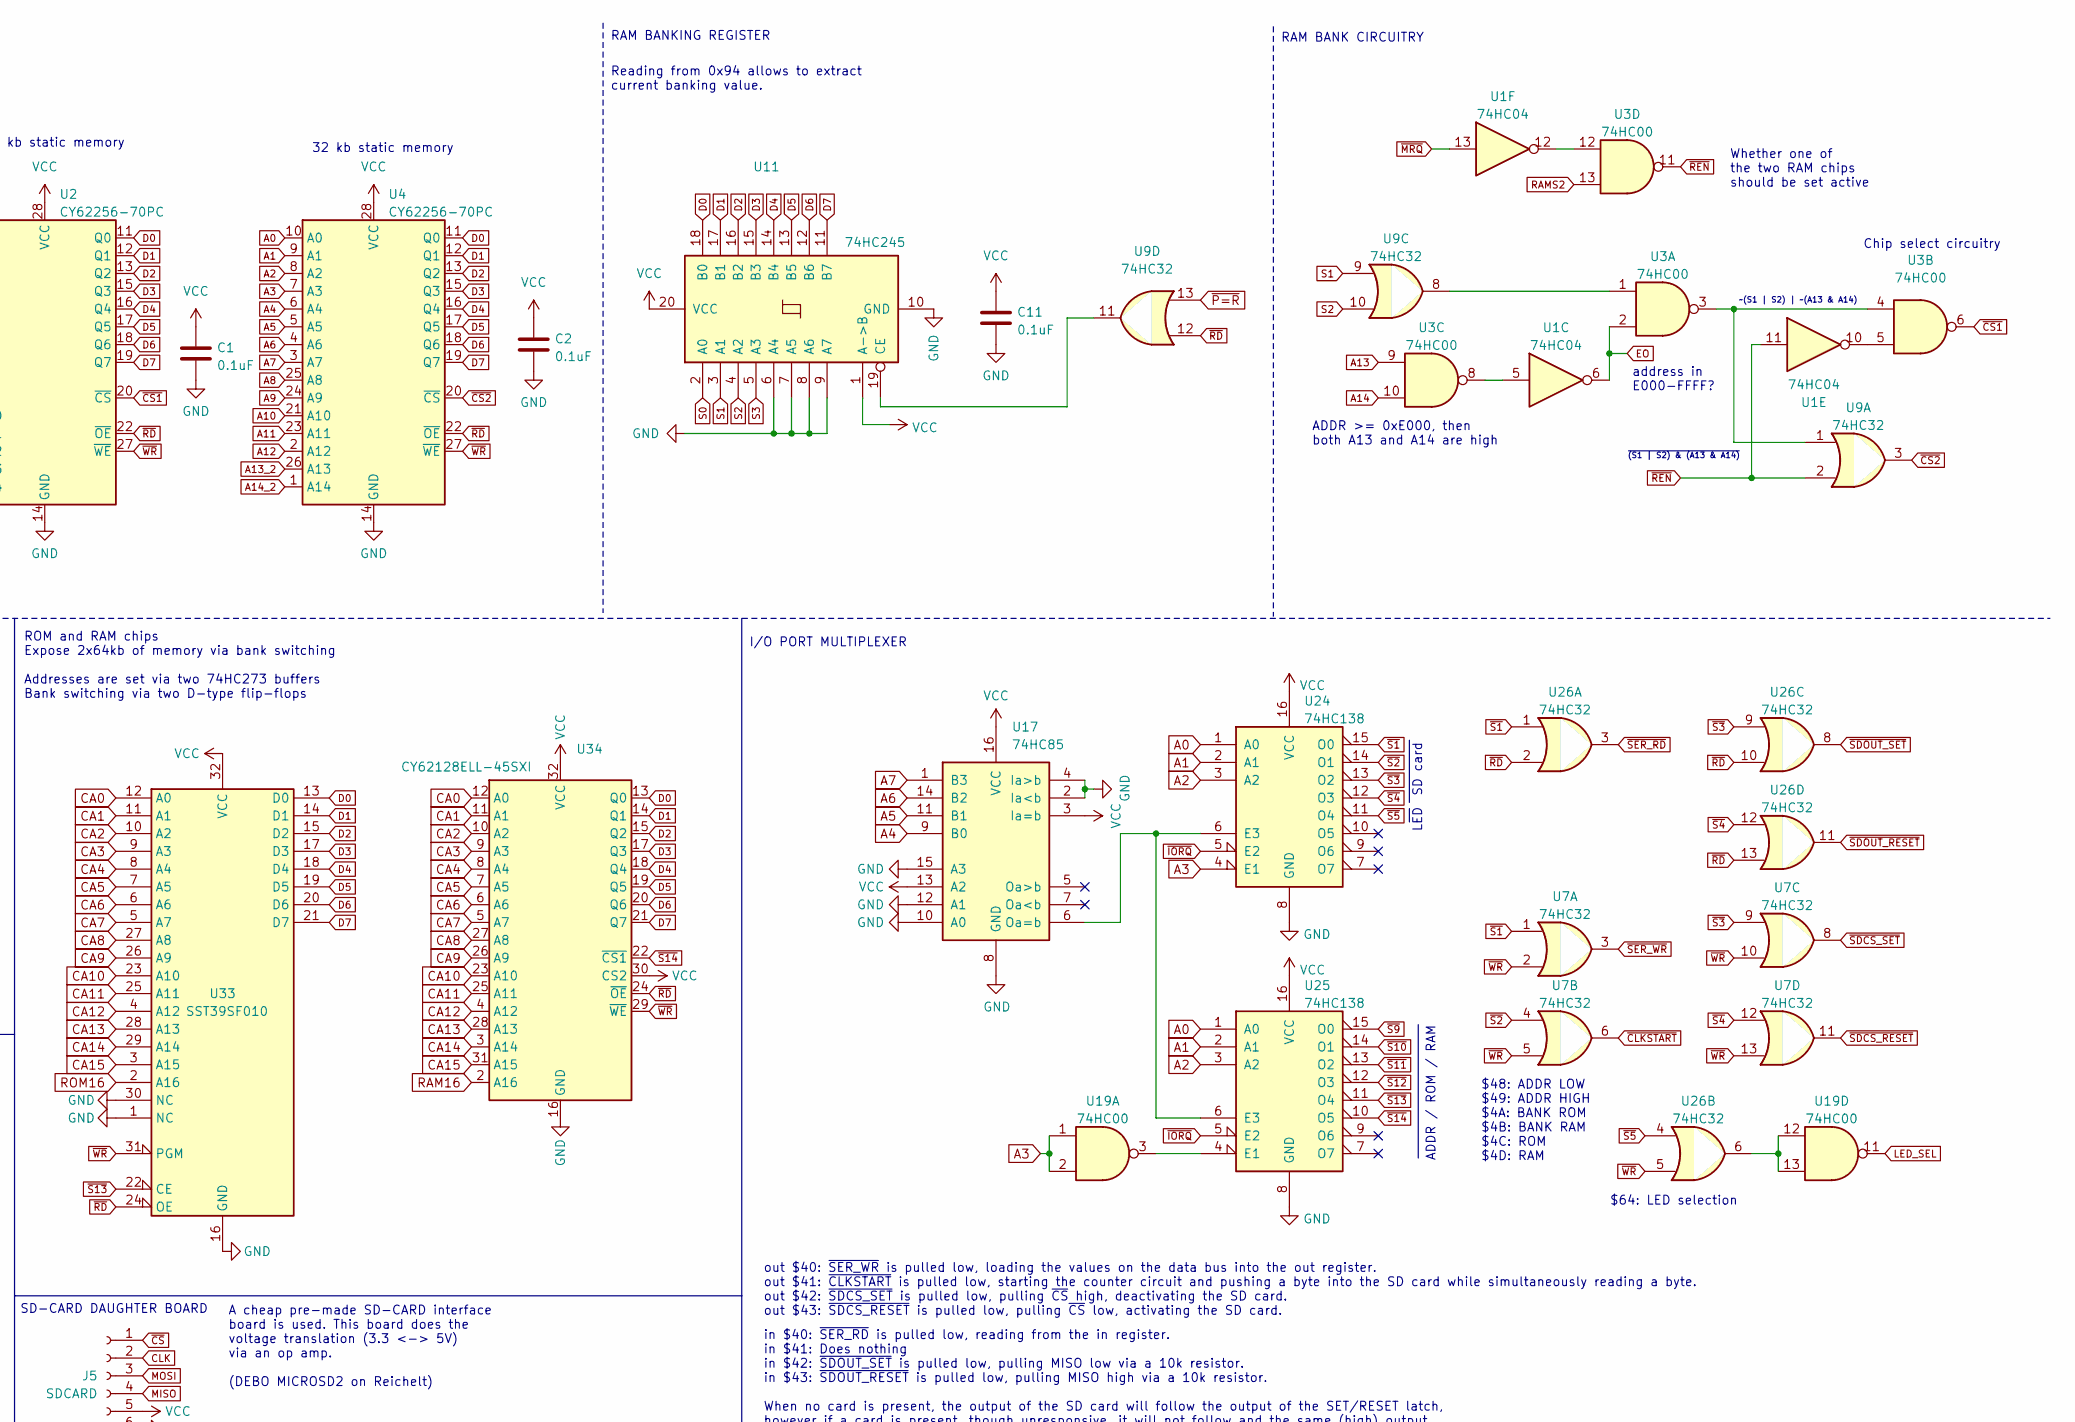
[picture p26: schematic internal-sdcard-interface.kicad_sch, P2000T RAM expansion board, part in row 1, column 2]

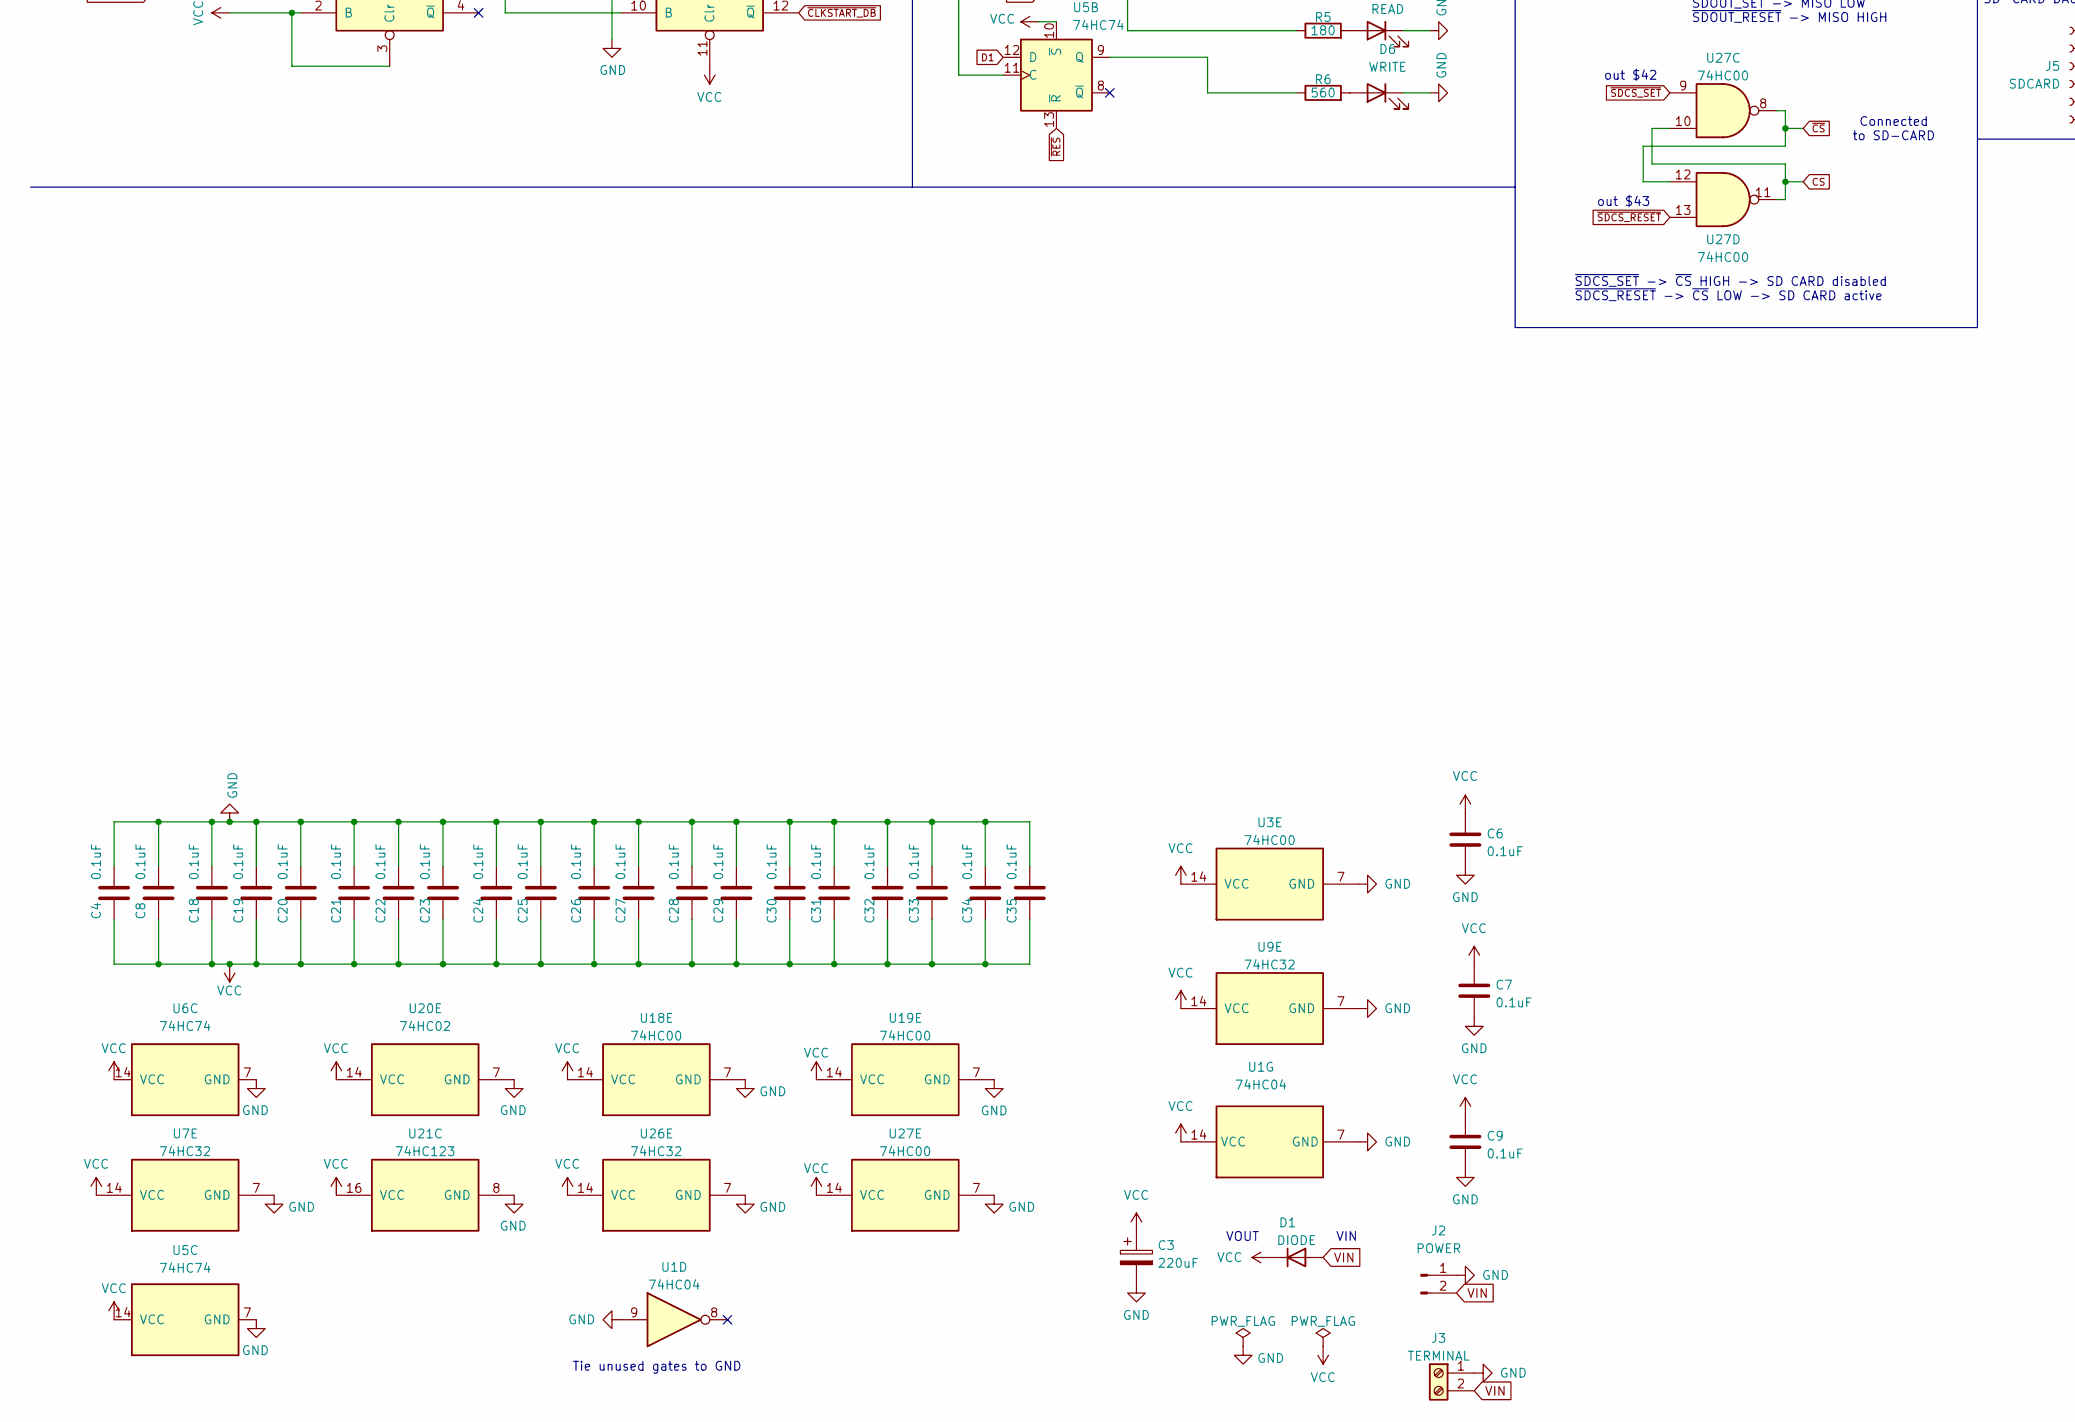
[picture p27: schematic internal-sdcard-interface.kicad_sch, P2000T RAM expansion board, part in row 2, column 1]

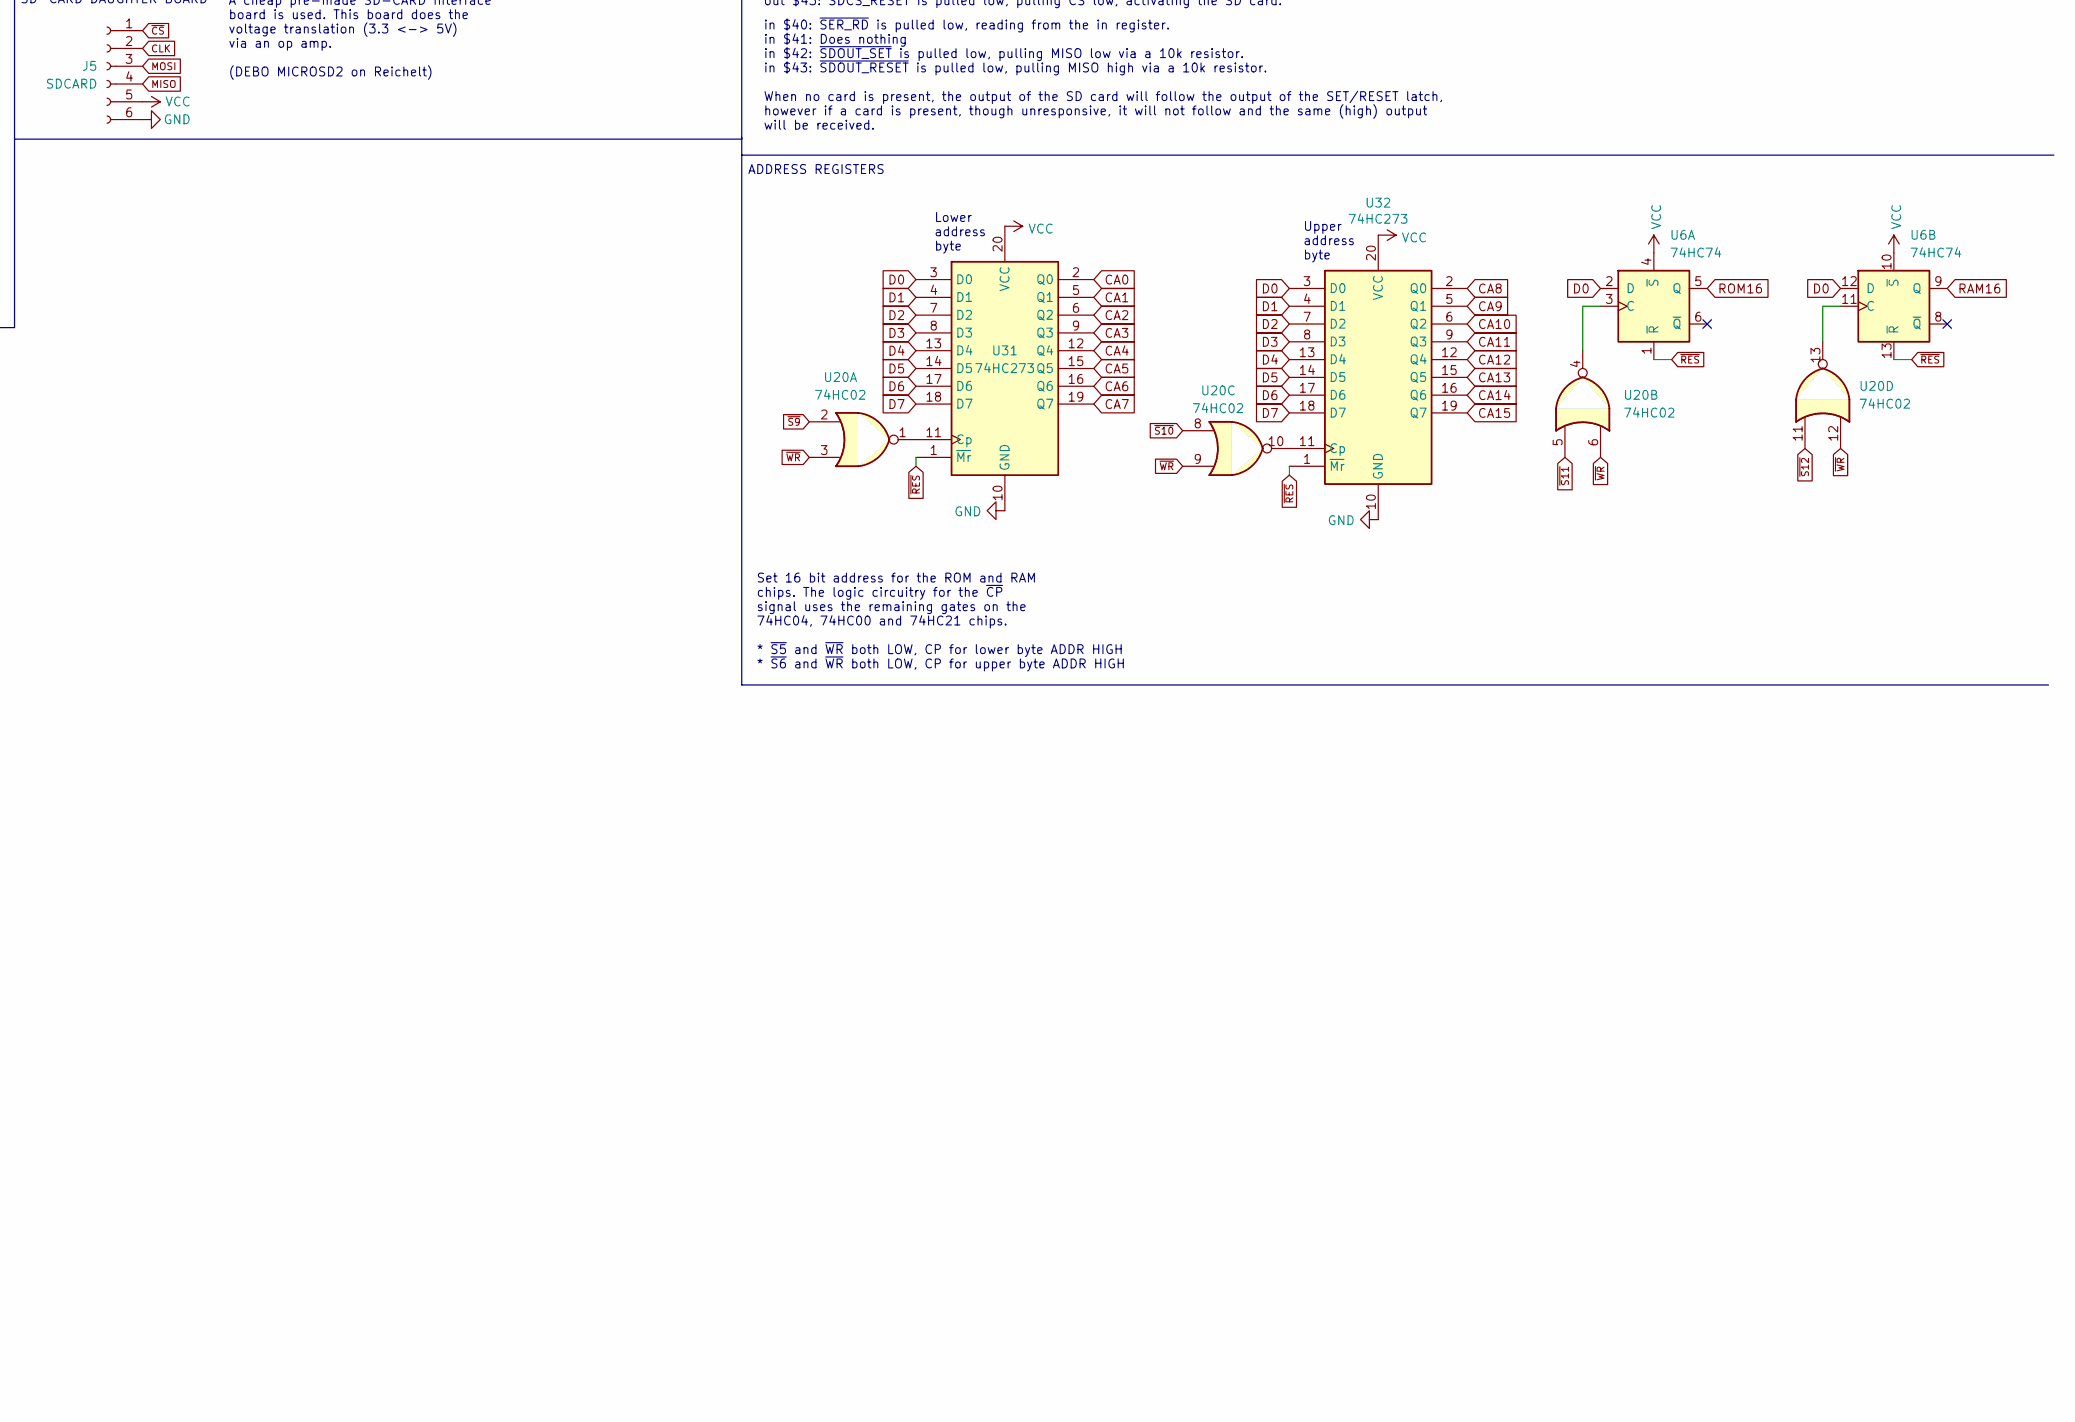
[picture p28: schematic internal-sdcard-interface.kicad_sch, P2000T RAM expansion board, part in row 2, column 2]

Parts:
C1, C2, C5, C6, C7, C9, C10, C11, C12: 0.1uF; C_Disc_D5.0mm_W2.5mm_P5.00mm
C3: 220uF; CP_Radial_D6.3mm_P2.50mm
C4, C8, C18, C19, C20, C21, C22, C23, C24, C25, C26, C27, C28, C29, C30, C31, C32, C33, C34, C35: 0.1uF; C_Disc_D5.0mm_W2.5mm_P5.00mm; LCSC Part # C126469
C37, C38: 22pF; C_Disc_D5.0mm_W2.5mm_P5.00mm; LCSC Part # C525286
D1: DIODE; D_DO-35_SOD27_P7.62mm_Horizontal
D3: SEL; LED_D5.0mm
D4: ACT; LED_D5.0mm
D5: READ; LED_D5.0mm
D6: WRITE; LED_D5.0mm
J1: EXPANSION BOARD; IDC-Header_2x20_P2.54mm_Vertical
J2: POWER; PinHeader_1x02_P2.54mm_Vertical
J3: TERMINAL; TerminalBlock_bornier-2_P5.08mm
J5: SDCARD; sdcard-socket
R5: 180; R_Axial_DIN0207_L6.3mm_D2.5mm_P7.62mm_Horizontal; LCSC Part # C429158
R6, R7: 560; R_Axial_DIN0207_L6.3mm_D2.5mm_P7.62mm_Horizontal; LCSC Part # C429158
R8: 0; R_Axial_DIN0207_L6.3mm_D2.5mm_P7.62mm_Horizontal; LCSC Part # C431818
R9, R10: 10k; R_Axial_DIN0207_L6.3mm_D2.5mm_P7.62mm_Horizontal; LCSC Part # C5159708
R11: 1k; R_Axial_DIN0207_L6.3mm_D2.5mm_P7.62mm_Horizontal; LCSC Part # C5123594
U1: 74HC04; DIP-14_W7.62mm_Socket
U2, U4: CY62256-70PC; DIP-28_W15.24mm_Socket
U3: 74HC00; DIP-14_W7.62mm_Socket
U5, U6: 74HC74; DIP-14_W7.62mm_Socket; LCSC Part # C27597
U7, U26: 74HC32; DIP-14_W7.62mm_Socket; LCSC Part # C5632
U8: 74HC688; DIP-20_W7.62mm_Socket
U9: 74HC32; DIP-14_W7.62mm_Socket
U10: 74HC173; DIP-16_W7.62mm_Socket
U11: 74HC245; DIP-20_W7.62mm_Socket
U12: 74HC157; DIP-16_W7.62mm_Socket
U17: 74HC85; DIP-16_W7.62mm_Socket; LCSC Part # C5953
U18, U19, U27: 74HC00; DIP-14_W7.62mm_Socket; LCSC Part # C699445
U20: 74HC02; DIP-14_W7.62mm_Socket; LCSC Part # C5588
U21: 74HC123; DIP-16_W7.62mm_Socket; LCSC Part # C5597
U23: 74HC163; DIP-16_W7.62mm_Socket; LCSC Part # C338758
U24, U25: 74HC138; DIP-16_W7.62mm_Socket; LCSC Part # C5602
U29: 74HC165; DIP-16_W7.62mm_Socket; LCSC Part # C5613
U30: 74HC595; DIP-16_W7.62mm_Socket; LCSC Part # C5947
U31, U32: 74HC273; DIP-20_W7.62mm_Socket; LCSC Part # C131486
U33: SST39SF010; PLCC-32_THT-Socket
U34: CY62128ELL-45SXI; SSOP-32_11.305x20.495mm_P1.27mm; LCSC Part # C2840304
X1: 16MHz; Oscillator_DIP-14

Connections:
16MHz: U23.2 (CP), X1.8 (OUT)
A0: J1.11, U2.10 (A0), U4.10 (A0), U8.2 (P0), U24.1 (A0), U25.1 (A0)
A1: J1.12, U2.9 (A1), U4.9 (A1), U8.4 (P1), U24.2 (A1), U25.2 (A1)
A2: J1.13, U2.8 (A2), U4.8 (A2), U8.6 (P2), U24.3 (A2), U25.3 (A2)
A3: J1.14, U2.7 (A3), U4.7 (A3), U8.8 (P3), U19.1, U19.2, U24.4 (E1)
A4: J1.15, U2.6 (A4), U4.6 (A4), U8.11 (P4), U17.9 (B0)
A5: J1.16, U2.5 (A5), U4.5 (A5), U8.13 (P5), U17.11 (B1)
A6: J1.17, U2.4 (A6), U4.4 (A6), U8.15 (P6), U17.14 (B2)
A7: J1.18, U2.3 (A7), U4.3 (A7), U8.17 (P7), U17.1 (B3)
A8: J1.19, U2.25 (A8), U4.25 (A8)
A9: J1.20, U2.24 (A9), U4.24 (A9)
A10: J1.21, U2.21 (A10), U4.21 (A10)
A11: J1.22, U2.23 (A11), U4.23 (A11)
A12: J1.23, U2.2 (A12), U4.2 (A12)
A13: J1.24, U3.9, U12.2 (I0a)
A13_1: U2.26 (A13), U12.4 (Za)
A13_2: U4.26 (A13), U12.9 (Zc)
A14: J1.25, U3.10
A14_1: U2.1 (A14), U12.7 (Zb)
A14_2: U4.1 (A14), U12.12 (Zd)
CA0: U31.2 (Q0), U33.12 (A0), U34.12 (A0)
CA1: U31.5 (Q1), U33.11 (A1), U34.11 (A1)
CA2: U31.6 (Q2), U33.10 (A2), U34.10 (A2)
CA3: U31.9 (Q3), U33.9 (A3), U34.9 (A3)
CA4: U31.12 (Q4), U33.8 (A4), U34.8 (A4)
CA5: U31.15 (Q5), U33.7 (A5), U34.7 (A5)
CA6: U31.16 (Q6), U33.6 (A6), U34.6 (A6)
CA7: U31.19 (Q7), U33.5 (A7), U34.5 (A7)
CA8: U32.2 (Q0), U33.27 (A8), U34.27 (A8)
CA9: U32.5 (Q1), U33.26 (A9), U34.26 (A9)
CA10: U32.6 (Q2), U33.23 (A10), U34.23 (A10)
CA11: U32.9 (Q3), U33.25 (A11), U34.25 (A11)
CA12: U32.12 (Q4), U33.4 (A12), U34.4 (A12)
CA13: U32.15 (Q5), U33.28 (A13), U34.28 (A13)
CA14: U32.16 (Q6), U33.29 (A14), U34.3 (A14)
CA15: U32.19 (Q7), U33.3 (A15), U34.31 (A15)
CLK: J5.2, U18.12, U18.13, U23.14 (Q0), U30.11 (SRCLK)
CLKSTOP: U18.9, U18.10, U23.15 (TC)
CS: U19.4, U19.9, U19.10, U27.10, U27.11
D0: J1.3, U2.11 (Q0), U4.11 (Q0), U5.2 (D), U6.2 (D), U6.12 (D), U10.14 (D0), U11.18 (B0), U29.11 (D0), U30.15 (QA), U31.3 (D0), U32.3 (D0), U33.13 (D0), U34.13 (Q0)
D1: J1.4, U2.12 (Q1), U4.12 (Q1), U5.12 (D), U10.13 (D1), U11.17 (B1), U29.12 (D1), U30.1 (QB), U31.4 (D1), U32.4 (D1), U33.14 (D1), U34.14 (Q1)
D2: J1.5, U2.13 (Q2), U4.13 (Q2), U10.12 (D2), U11.16 (B2), U29.13 (D2), U30.2 (QC), U31.7 (D2), U32.7 (D2), U33.15 (D2), U34.15 (Q2)
D3: J1.6, U2.15 (Q3), U4.15 (Q3), U10.11 (D3), U11.15 (B3), U29.14 (D3), U30.3 (QD), U31.8 (D3), U32.8 (D3), U33.17 (D3), U34.17 (Q3)
D4: J1.7, U2.16 (Q4), U4.16 (Q4), U11.14 (B4), U29.3 (D4), U30.4 (QE), U31.13 (D4), U32.13 (D4), U33.18 (D4), U34.18 (Q4)
D5: J1.8, U2.17 (Q5), U4.17 (Q5), U11.13 (B5), U29.4 (D5), U30.5 (QF), U31.14 (D5), U32.14 (D5), U33.19 (D5), U34.19 (Q5)
D6: J1.9, U2.18 (Q6), U4.18 (Q6), U11.12 (B6), U29.5 (D6), U30.6 (QG), U31.17 (D6), U32.17 (D6), U33.20 (D6), U34.20 (Q6)
D7: J1.10, U2.19 (Q7), U4.19 (Q7), U11.11 (B7), U29.6 (D7), U30.7 (QH), U31.18 (D7), U32.18 (D7), U33.21 (D7), U34.21 (Q7)
EO: U1.6, U3.2, U12.1 (S)
GND: C1.2, C2.2, C3.2, C4.2, C5.2, C6.2, C7.2, C8.2, C9.2, C10.2, C11.2, C12.2, C18.2, C19.2, C20.2, C21.2, C22.2, C23.2, C24.2, C25.2, C26.2, C27.2, C28.2, C29.2, C30.2, C31.2, C32.2, C33.2, C34.2, C35.2, D5.1 (K), D6.1 (K), J1.1, J2.1, J3.1, J5.6, U1.7 (GND), U1.9, U2.14 (GND), U3.7 (GND), U4.14 (GND), U5.7 (GND), U6.7 (GND), U7.7 (GND), U8.3 (R0), U8.5 (R1), U8.9 (R3), U8.10 (GND), U8.14 (R5), U8.16 (R6), U9.7 (GND), U10.1 (Oe1), U10.2 (Oe2), U10.8 (GND), U10.9 (E1), U10.10 (E2), U11.6 (A4), U11.7 (A5), U11.8 (A6), U11.9 (A7), U11.10 (GND), U12.5 (I0b), U12.8 (GND), U12.15 (E), U17.2 (Ia<b), U17.4 (Ia>b), U17.8 (GND), U17.10 (A0), U17.12 (A1), U17.15 (A3), U18.7 (GND), U19.7 (GND), U20.7 (GND), U21.8 (GND), U21.9 (A), U23.3 (D0), U23.4 (D1), U23.5 (D2), U23.6 (D3), U23.8 (GND), U24.8 (GND), U25.8 (GND), U26.7 (GND), U27.7 (GND), U29.8 (GND), U29.15 (~CE), U30.8 (GND), U31.10 (GND), U32.10 (GND), U33.1 (NC), U33.16 (GND), U33.30 (NC), U34.16 (GND), X1.7 (GND)
LED_SEL: U5.3 (C), U5.11 (C), U19.11
MISO: J5.4, R10.2, U30.14 (SER)
MOSI: J5.3, U29.9 (Q7)
unnamed: D3.2 (A), R7.1
unnamed: D3.1 (K), U19.8
unnamed: D4.2 (A), R8.1
unnamed: D4.1 (K), U19.6
unnamed: D5.2 (A), R5.2
unnamed: D6.2 (A), R6.2
unnamed: R10.1, U27.2, U27.6
unnamed: U1.3, U9.6
unnamed: U1.5, U3.8
unnamed: U1.10, U3.5
unnamed: U1.12, U3.12
unnamed: U3.1, U9.8
unnamed: U3.3, U3.4, U9.1
unnamed: R5.1, U5.5 (Q)
unnamed: R6.1, U5.9 (Q)
unnamed: U6.3 (C), U20.4
unnamed: U6.11 (C), U20.13
unnamed: U1.4, U10.7 (Cp)
unnamed: U9.11, U11.19 (CE)
unnamed: U17.6 (Oa=b), U24.6 (E3), U25.6 (E3)
unnamed: U18.3, U18.4
unnamed: U19.12, U19.13, U26.6
unnamed: C37.1, U21.14 (Cext)
unnamed: U21.10 (B), U21.13 (Q)
unnamed: C37.2, R9.2, U21.15 (RCext)
unnamed: C38.1, U21.6 (Cext)
unnamed: C38.2, R11.1, U21.7 (RCext)
unnamed: U19.3, U25.4 (E1)
unnamed: U27.3, U27.4
unnamed: U20.1, U31.11 (Cp)
unnamed: U20.10, U32.11 (Cp)
RAM16: U6.9 (Q), U34.2 (A16)
RAMS2: J1.26, U3.13
RES: U1.2, U10.15 (Mr)
ROM16: U6.5 (Q), U33.2 (A16)
S0: U10.3 (Q0), U11.2 (A0), U12.3 (I1a), U12.10 (I1c), U12.11 (I0c)
S1: U9.9, U10.4 (Q1), U11.3 (A1)
S2: U9.10, U10.5 (Q2), U11.4 (A2), U12.13 (I1d), U12.14 (I0d)
S3: U10.6 (Q3), U11.5 (A3)
SD_SPI: U18.2, U18.6, U19.5, U23.1 (~MR)
VCC: C1.1, C2.1, C3.1, C4.1, C5.1, C6.1, C7.1, C8.1, C9.1, C10.1, C11.1, C12.1, C18.1, C19.1, C20.1, C21.1, C22.1, C23.1, C24.1, C25.1, C26.1, C27.1, C28.1, C29.1, C30.1, C31.1, C32.1, C33.1, C34.1, C35.1, D1.1 (K), J5.5, R7.2, R8.2, R9.1, R11.2, U1.14 (VCC), U2.28 (VCC), U3.14 (VCC), U4.28 (VCC), U5.4 (~S), U5.10 (~S), U5.14 (VCC), U6.4 (~S), U6.10 (~S), U6.14 (VCC), U7.14 (VCC), U8.7 (R2), U8.12 (R4), U8.18 (R7), U8.20 (VCC), U9.14 (VCC), U10.16 (VCC), U11.1 (A->B), U11.20 (VCC), U12.6 (I1b), U12.16 (VCC), U17.3 (Ia=b), U17.13 (A2), U17.16 (VCC), U18.14 (VCC), U19.14 (VCC), U20.14 (VCC), U21.2 (B), U21.3 (Clr), U21.11 (Clr), U21.16 (VCC), U23.7 (CEP), U23.9 (~PE), U23.10 (CET), U23.16 (VCC), U24.16 (VCC), U25.16 (VCC), U26.14 (VCC), U27.14 (VCC), U29.10 (DS), U29.16 (VCC), U30.10 (~SRCLR), U30.16 (VCC), U31.20 (VCC), U32.20 (VCC), U33.32 (VCC), U34.30 (CS2), U34.32 (VCC), X1.14 (Vcc)
VIN: D1.2 (A), J2.2, J3.2
~CLKSTART_DB: U18.5, U21.12 (~Q)
~CLKSTART: U7.6, U21.1 (A)
~CLKSTOP: U18.1, U18.8
~CLK: U18.11, U29.2 (CP), U30.12 (RCLK)
~CS1: U2.20 (~CS), U3.6
~CS2: U4.20 (~CS), U9.3
~CS: J5.1, U27.8, U27.12
~IORQ: J1.31, U8.1 (G), U24.5 (E2), U25.5 (E2)
~MRQ: J1.27, U1.13
~P=R: U8.19 (P=R), U9.4, U9.13
~RD: J1.28, U2.22 (~OE), U4.22 (~OE), U9.12, U26.2, U26.10, U26.13, U33.24 (OE), U34.24 (~OE)
~REN: U1.11, U3.11, U9.2
~RES: J1.34, U1.1, U5.1 (~R), U5.13 (~R), U6.1 (~R), U6.13 (~R), U31.1 (~Mr), U32.1 (~Mr)
~S1: U7.1, U24.15 (O0), U26.1
~S2: U7.4, U24.14 (O1)
~S3: U7.9, U24.13 (O2), U26.9
~S4: U7.12, U24.12 (O3), U26.12
~S5: U24.11 (O4), U26.4
~S9: U20.2, U25.15 (O0)
~S10: U20.8, U25.14 (O1)
~S11: U20.5, U25.13 (O2)
~S12: U20.11, U25.12 (O3)
~S13: U25.11 (O4), U33.22 (CE)
~S14: U25.10 (O5), U34.22 (~CS1)
~SDCS_RESET: U7.11, U27.13
~SDCS_SET: U7.8, U27.9
~SDOUT_RESET: U26.11, U27.5
~SDOUT_SET: U26.8, U27.1
~SER_RD: U26.3, U30.13 (~OE)
~SER_WR: U7.3, U29.1 (~PL)
~WR: J1.30, U2.27 (~WE), U4.27 (~WE), U7.2, U7.5, U7.10, U7.13, U9.5, U20.3, U20.6, U20.9, U20.12, U26.5, U33.31 (PGM), U34.29 (~WE)

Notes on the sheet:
Lower address byte
SD CARD S/R LATCHES
Upper address byte
Reading from 0x94 allows to extract current banking value.
Via a ribbon cable, this 40 pin interface port is connected to the main board of the P2000T.
32 kb static memory
EXPANSION BOARD CONNECTOR
RAM Access Memory 2
1k resistor with 22pF cap gives 0.45*RC = 0.01us active low pulse
Whether one of the two RAM chips should be set active
Two LEDS show whether the SD card is selected via the CS line and whether signals are sent to the SD card. Another two leds show I/O on the RAM and ROM chips.
This components gives the clock signal to drive the SPI protocol. Although it was designed around a 16 MHz osscillator, benchmarks indicate that any frequency between 4 - 16.25 MHz works fine.
out $40: ~{SER_WR} is pulled low, loading the values on the data bus into the out register. out $41: ~{CLKSTART} is pulled low, starting the counter circuit and pushing a byte into the SD card while simultaneously reading a byte. out $42: ~{SDCS_SET} is pulled low, pulling ~{CS} high, deactivating 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
A cheap pre-made SD-CARD interface board is used. This board does the voltage translation (3.3 <-> 5V) via an op amp. (DEBO MICROSD2 on Reichelt)
0x94
~{INT} ~{IORQ} ~{M1} ~{LOCK} ~{DEW/R2425} PHI2
ROM and RAM chips Expose 2x64kb of memory via bank switching Addresses are set via two 74HC273 buffers Bank switching via two D-type flip-flops
~{SDCS_SET} -> ~{CS} HIGH -> SD CARD disabled ~{SDCS_RESET} -> ~{CS} LOW -> SD CARD active
out $42
RAM BANKING REGISTER
I/O PORT MULTIPLEXER
~{(S1 | S2) & (A13 & A14)}
~{SDOUT_SET} -> MISO LOW ~{SDOUT_RESET} -> MISO HIGH
Tie unused gates to GND
SD card
RAM BANK CIRCUITRY
On ~{CLKSTART}, this component produces exactly 8 pulses at 8MHz.
Connected to SD-CARD
Active high reset needed for 74HC173
Only active on ~{IORQ}
Because of timing contraints, ~{WR} needs to be combined with ~{P=R}
address in E000-FFFF?
out $43
ADDR / ROM / RAM
10k resistor with 22pF cap gives t = 0.45RC = 0.1us delay between consecutive pulses
Both CEP and CET need to be high for count to be enabled.
SHIFT REGISTER SD -> Z80 IN REGISTER
On ~{CLKSTART}, ~{MR} will be set HIGH, activating the counter.
ADDR >= 0xE000, then both A13 and A14 are high
MULTIVIBRATOR DELAY COMPONENT

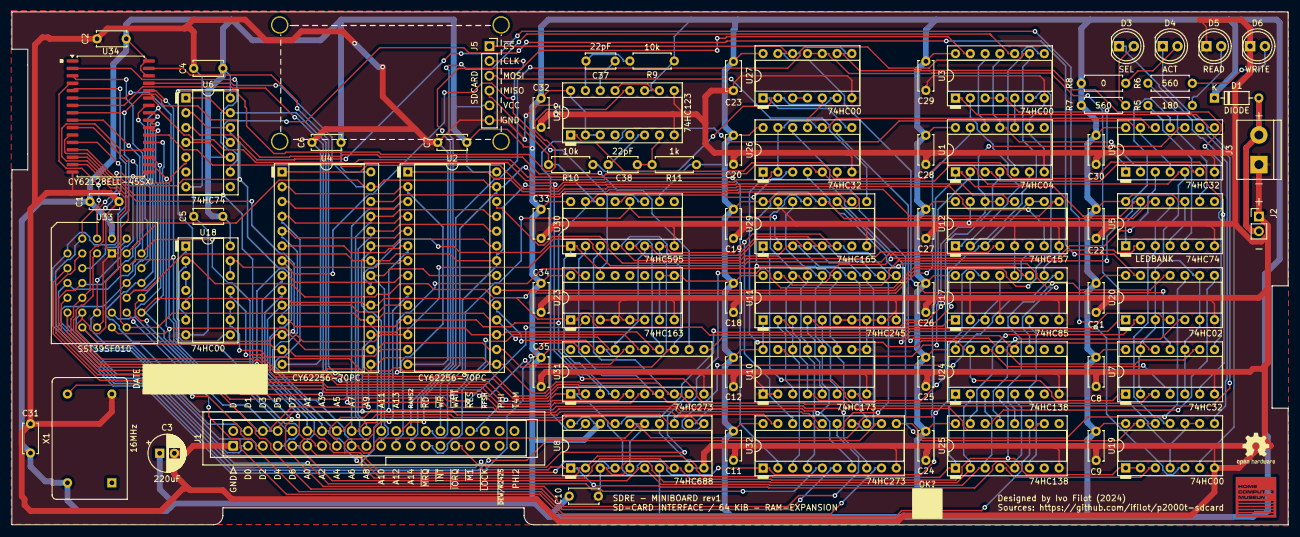
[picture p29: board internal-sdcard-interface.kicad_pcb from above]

Board: 2 copper layers, 219.0 x 88.0 mm, 78 parts (0 on the bottom side), 125 nets.

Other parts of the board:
G001: LOGO; hcm_logo

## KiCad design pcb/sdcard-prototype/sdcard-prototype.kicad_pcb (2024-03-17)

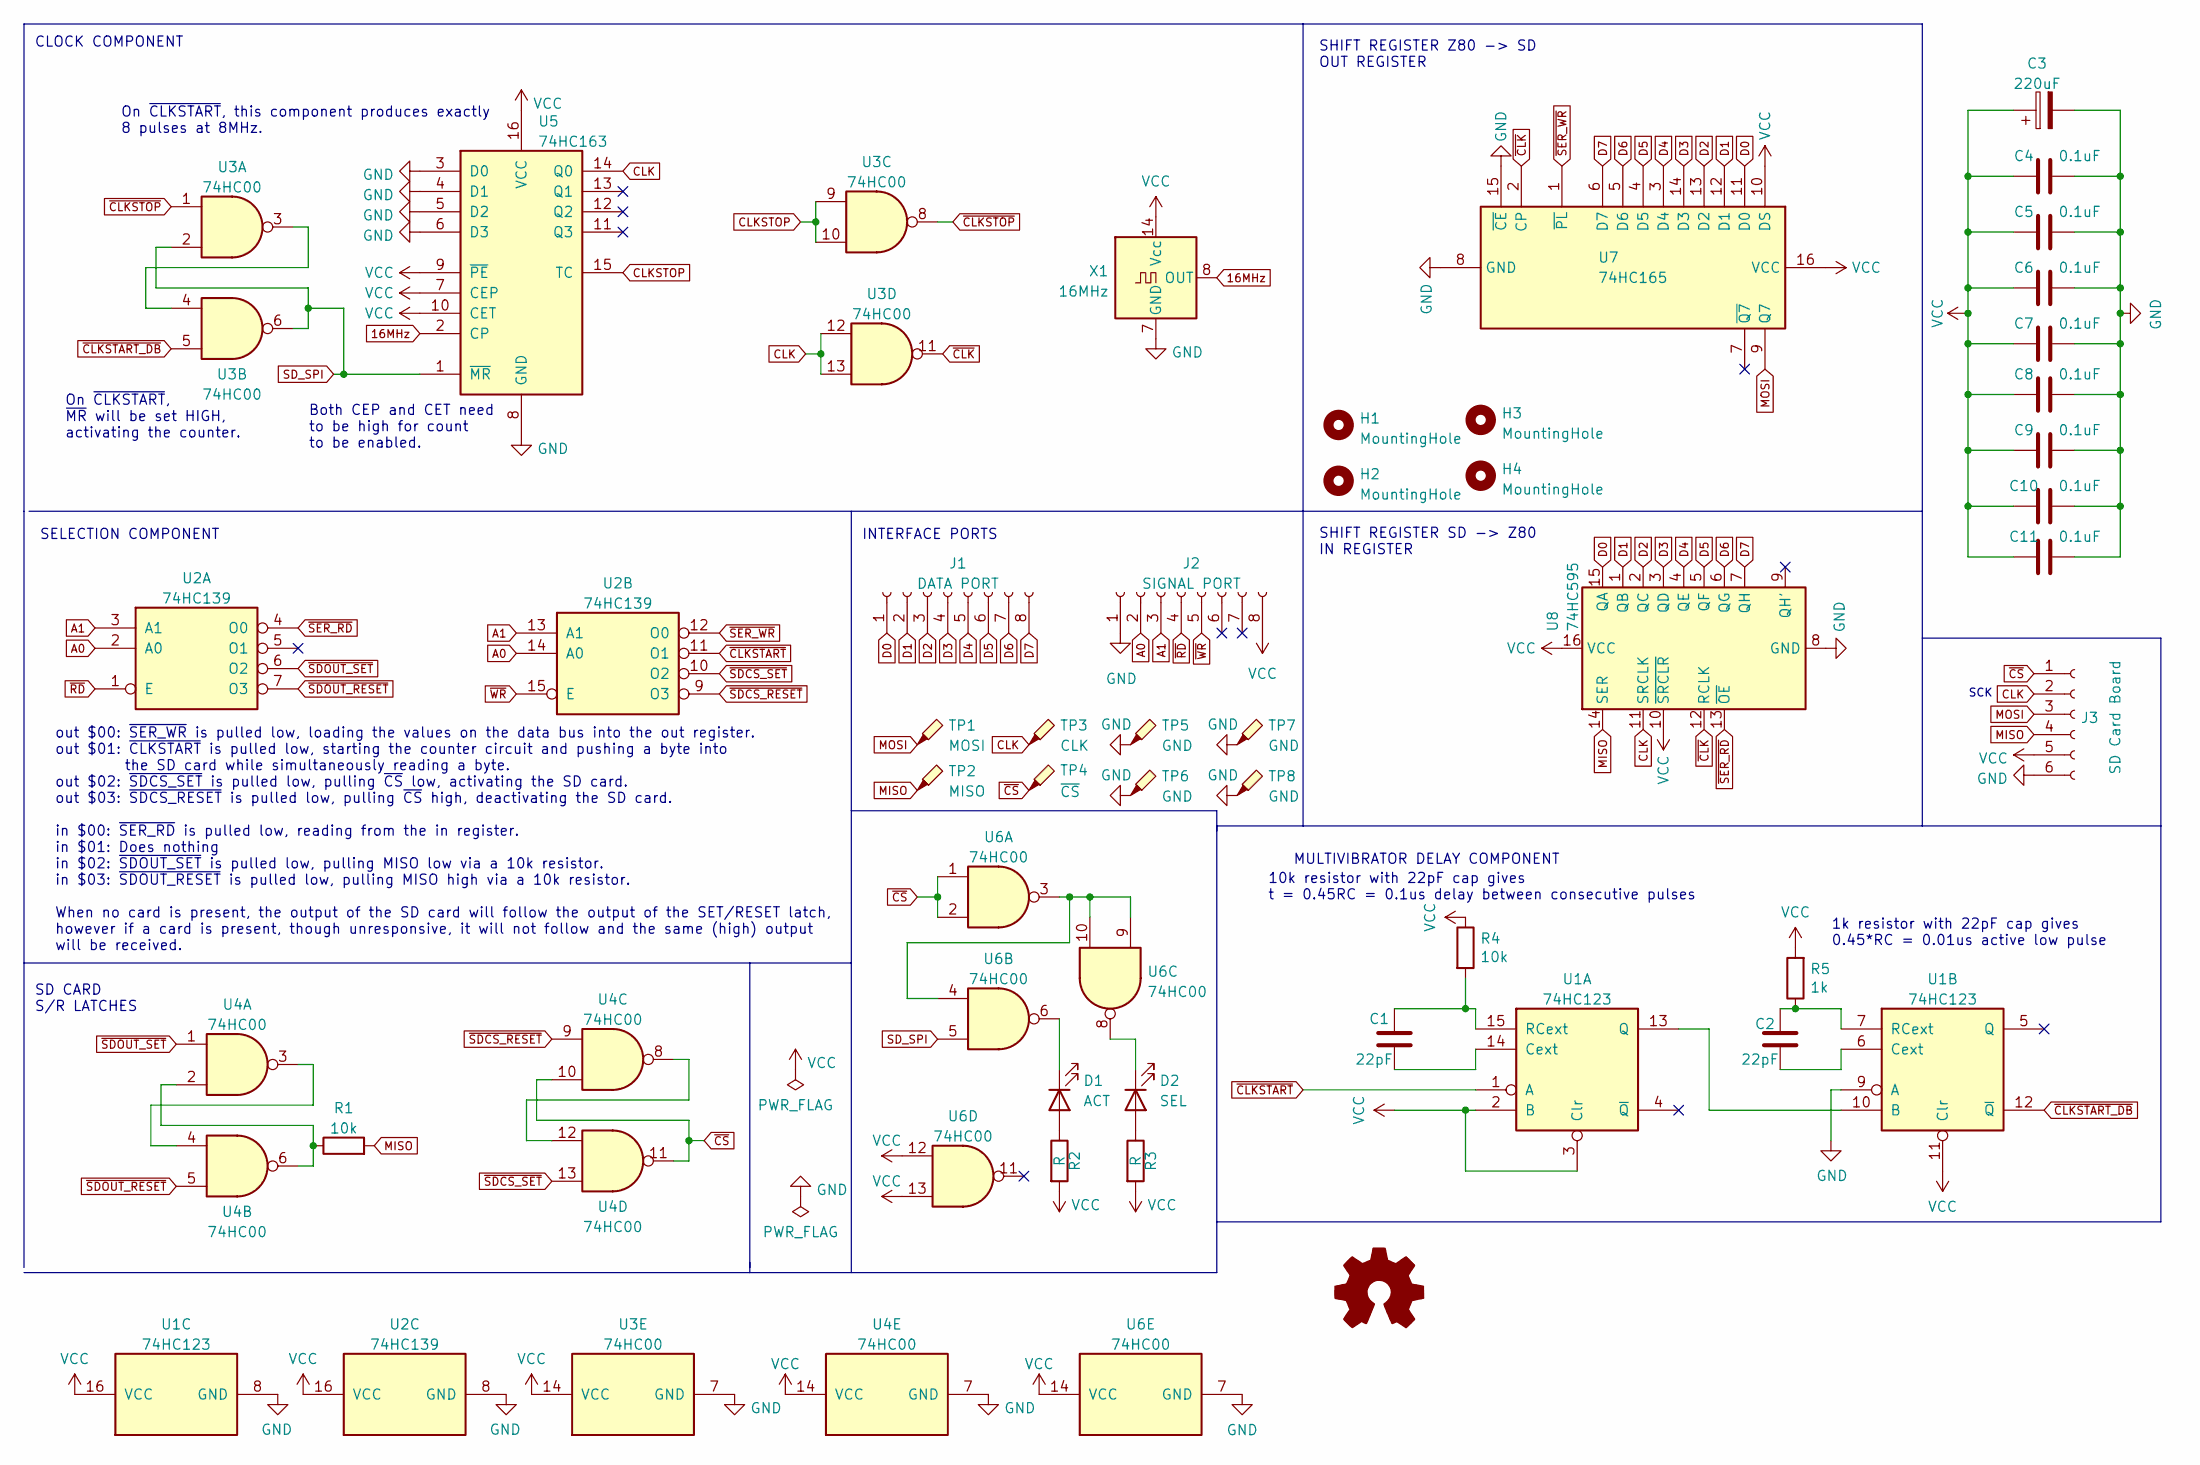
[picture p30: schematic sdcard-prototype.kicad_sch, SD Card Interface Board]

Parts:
C1, C2: 22pF; C_Disc_D5.0mm_W2.5mm_P5.00mm
C3: 220uF; CP_Radial_D6.3mm_P2.50mm
C4, C5, C6, C7, C8, C9, C10, C11: 0.1uF; C_Disc_D5.0mm_W2.5mm_P5.00mm
D1: ACT; LED_D5.0mm
D2: SEL; LED_D5.0mm
H1, H2, H3, H4: MountingHole; MountingHole_3.2mm_M3_DIN965
J1: DATA PORT; PinSocket_1x08_P2.54mm_Vertical
J2: SIGNAL PORT; PinSocket_1x08_P2.54mm_Vertical
J3: SD Card Board; PinSocket_1x06_P2.54mm_Vertical
R1, R4: 10k; R_Axial_DIN0207_L6.3mm_D2.5mm_P7.62mm_Horizontal
R2, R3: R; R_Axial_DIN0207_L6.3mm_D2.5mm_P7.62mm_Horizontal
R5: 1k; R_Axial_DIN0207_L6.3mm_D2.5mm_P7.62mm_Horizontal
TP1: MOSI; TestPoint_THTPad_2.5x2.5mm_Drill1.2mm
TP2: MISO; TestPoint_THTPad_2.5x2.5mm_Drill1.2mm
TP3: CLK; TestPoint_THTPad_2.5x2.5mm_Drill1.2mm
TP4: ~{CS}; TestPoint_THTPad_2.5x2.5mm_Drill1.2mm
TP5, TP6, TP7, TP8: GND; TestPoint_Pad_4.0x4.0mm
U1: 74HC123; DIP-16_W7.62mm_Socket
U2: 74HC139; DIP-16_W7.62mm_Socket
U3, U4, U6: 74HC00; DIP-14_W7.62mm_Socket
U5: 74HC163; DIP-16_W7.62mm_Socket
U7: 74HC165; DIP-16_W7.62mm_Socket
U8: 74HC595; DIP-16_W7.62mm_Socket
X1: 16MHz; Oscillator_DIP-14

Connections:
16MHz: U5.2 (CP), X1.8 (OUT)
A0: J2.2, U2.2 (A0), U2.14 (A0)
A1: J2.3, U2.3 (A1), U2.13 (A1)
CLK: J3.2, TP3.1, U3.12, U3.13, U5.14 (Q0), U8.11 (SRCLK)
CLKSTOP: U3.9, U3.10, U5.15 (TC)
D0: J1.1, U7.11 (D0), U8.15 (QA)
D1: J1.2, U7.12 (D1), U8.1 (QB)
D2: J1.3, U7.13 (D2), U8.2 (QC)
D3: J1.4, U7.14 (D3), U8.3 (QD)
D4: J1.5, U7.3 (D4), U8.4 (QE)
D5: J1.6, U7.4 (D5), U8.5 (QF)
D6: J1.7, U7.5 (D6), U8.6 (QG)
D7: J1.8, U7.6 (D7), U8.7 (QH)
GND: C3.2, C4.2, C5.2, C6.2, C7.2, C8.2, C9.2, C10.2, C11.2, J2.1, J3.6, TP5.1, TP6.1, TP7.1, TP8.1, U1.8 (GND), U1.9 (A), U2.8 (GND), U3.7 (GND), U4.7 (GND), U5.3 (D0), U5.4 (D1), U5.5 (D2), U5.6 (D3), U5.8 (GND), U6.7 (GND), U7.8 (GND), U7.15 (~CE), U8.8 (GND), X1.7 (GND)
MISO: J3.4, R1.2, TP2.1, U8.14 (SER)
MOSI: J3.3, TP1.1, U7.9 (Q7)
unnamed: C1.1, U1.14 (Cext)
unnamed: C1.2, R4.2, U1.15 (RCext)
unnamed: C2.1, U1.6 (Cext)
unnamed: C2.2, R5.1, U1.7 (RCext)
unnamed: D1.1 (K), U6.6
unnamed: D1.2 (A), R2.1
unnamed: D2.1 (K), U6.8
unnamed: D2.2 (A), R3.1
unnamed: R1.1, U4.2, U4.6
unnamed: U1.10 (B), U1.13 (Q)
unnamed: U3.3, U3.4
unnamed: U4.3, U4.4
unnamed: U4.8, U4.12
unnamed: U6.3, U6.4, U6.9, U6.10
SD_SPI: U3.2, U3.6, U5.1 (~MR), U6.5
VCC: C3.1, C4.1, C5.1, C6.1, C7.1, C8.1, C9.1, C10.1, C11.1, J2.8, J3.5, R2.2, R3.2, R4.1, R5.2, U1.2 (B), U1.3 (Clr), U1.11 (Clr), U1.16 (VCC), U2.16 (VCC), U3.14 (VCC), U4.14 (VCC), U5.7 (CEP), U5.9 (~PE), U5.10 (CET), U5.16 (VCC), U6.12, U6.13, U6.14 (VCC), U7.10 (DS), U7.16 (VCC), U8.10 (~SRCLR), U8.16 (VCC), X1.14 (Vcc)
~CLKSTART_DB: U1.12 (~Q), U3.5
~CLKSTART: U1.1 (A), U2.11 (O1)
~CLKSTOP: U3.1, U3.8
~CLK: U3.11, U7.2 (CP), U8.12 (RCLK)
~CS: J3.1, TP4.1, U4.10, U4.11, U6.1, U6.2
~RD: J2.4, U2.1 (E)
~SDCS_RESET: U2.9 (O3), U4.9
~SDCS_SET: U2.10 (O2), U4.13
~SDOUT_RESET: U2.7 (O3), U4.5
~SDOUT_SET: U2.6 (O2), U4.1
~SER_RD: U2.4 (O0), U8.13 (~OE)
~SER_WR: U2.12 (O0), U7.1 (~PL)
~WR: J2.5, U2.15 (E)

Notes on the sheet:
SHIFT REGISTER SD -> Z80 IN REGISTER
SD CARD S/R LATCHES
out $00: ~{SER_WR} is pulled low, loading the values on the data bus into the out register. out $01: ~{CLKSTART} is pulled low, starting the counter circuit and pushing a byte into the SD card while simultaneously reading a byte. out $02: ~{SDCS_SET} is pulled low, pulling ~{CS} low, activating the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
On ~{CLKSTART}, this component produces exactly 8 pulses at 8MHz.
On ~{CLKSTART}, ~{MR} will be set HIGH, activating the counter.
in $00: ~{SER_RD} is pulled low, reading from the in register. in $01: Does nothing in $02: ~{SDOUT_SET} is pulled low, pulling MISO low via a 10k resistor. in $03: ~{SDOUT_RESET} is pulled low, pulling MISO high via a 10k resistor. When no card is present, the output of the SD card will follow the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
SELECTION COMPONENT
1k resistor with 22pF cap gives 0.45*RC = 0.01us active low pulse
10k resistor with 22pF cap gives t = 0.45RC = 0.1us delay between consecutive pulses
CLOCK COMPONENT
INTERFACE PORTS
Both CEP and CET need to be high for count to be enabled.
SCK
MULTIVIBRATOR DELAY COMPONENT
SHIFT REGISTER Z80 -> SD OUT REGISTER

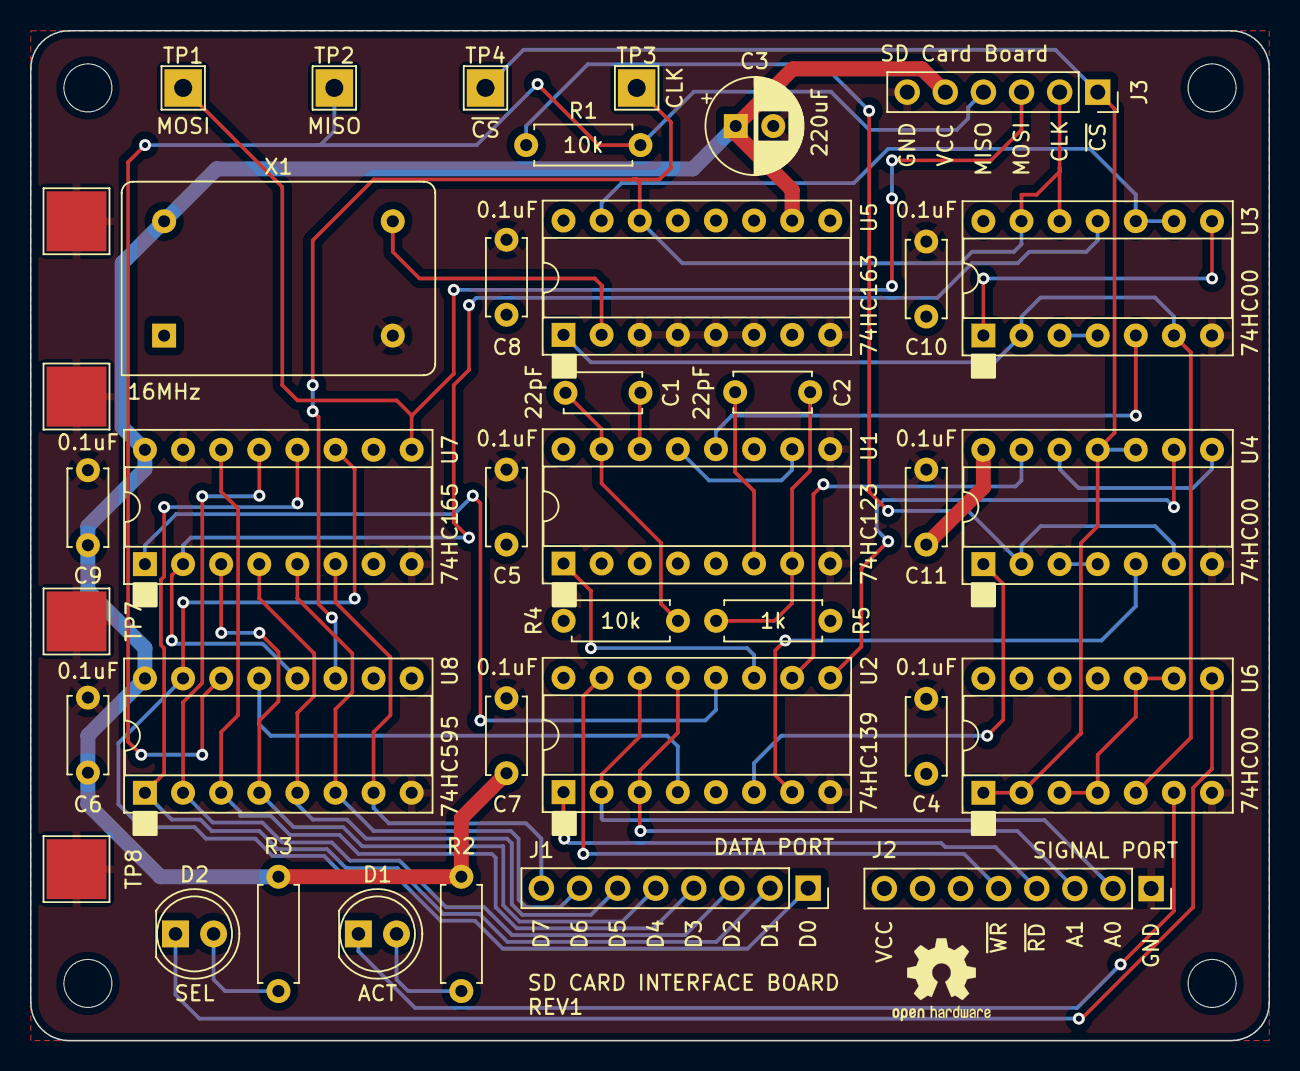
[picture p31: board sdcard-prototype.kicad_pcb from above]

Board: 2 copper layers, 82.5 x 67.3 mm, 42 parts (0 on the bottom side), 45 nets.

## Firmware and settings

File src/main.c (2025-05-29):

/**************************************************************************
 *                                                                        *
 *   Author: Ivo Filot <ivo@ivofilot.nl>                                  *
 *                                                                        *
 *   P2000T-SDCARD is free software:                                      *
 *   you can redistribute it and/or modify it under the terms of the      *
 *   GNU General Public License as published by the Free Software         *
 *   Foundation, either version 3 of the License, or (at your option)     *
 *   any later version.                                                   *
 *                                                                        *
 *   P2000T-SDCARD is distributed in the hope that it will be useful,     *
 *   but WITHOUT ANY WARRANTY; without even the implied warranty          *
 *   of MERCHANTABILITY or FITNESS FOR A PARTICULAR PURPOSE.              *
 *   See the GNU General Public License for more details.                 *
 *                                                                        *
 *   You should have received a copy of the GNU General Public License    *
 *   along with this program.  If not, see http://www.gnu.org/licenses/.  *
 *                                                                        *
 **************************************************************************/

#include <string.h>
#include <stdint.h>
#include <stdio.h>
#include <z80.h>

#include "commands.h"
#include "constants.h"
#include "ascii.h"
#include "config.h"
#include "ports.h"

// set printf io
#pragma printf "%i %X %lX %c %s %lu %u"

// definitions
void init(void);

void main(void) {
    // initialize environment
    init();

    // check if there is a file called "AUTOBOOT.CAS", if so, immediately
    // launch this CAS file
    uint32_t fcl = find_file(_root_dir_first_cluster, "AUTOBOOT", "CAS");
    if(fcl != 0) {
        print("Loading AUTOBOOT.CAS...");
        build_linked_list(fcl);
        set_ram_bank(RAM_BANK_CASSETTE);
        store_cas_ram(_linkedlist[0], 0x0000);
        set_ram_bank(0);
        return;
    }

    // put in infinite loop and wait for user commands
    for(;;) {
        if(keymem[0x0C] > 0) {
            for(uint8_t i=0; i<keymem[0x0C]; i++) {
                if(keymem[i] == 52) { // return key
                    memset(keymem, 0x00, 0x0D); // flush key buffer
                    execute_command();
                    break;
                }

                if(keymem[i] == 44) { // backspace key
                    if(__inputpos > 0) {
                        __inputpos--;
                        __input[__inputpos] = 0x00;
                    }
                    break;
                }

                if(__inputpos < INPUTLENGTH) {
                    __input[__inputpos] = __ascii[keymem[i]];
                    __inputpos++;
                }
            }

            // flush key buffer
            memset(keymem, 0x00, 0x0D);

            // place command on command line
            __input[__inputpos] = 0x00;
            sprintf(termbuffer, "%c>%c%s", COL_CYAN, COL_WHITE, __input);
            terminal_redoline();
        }

        // add a blinking cursor
        terminal_cursor_blink();
    }
}

void init(void) {
    // disable SD-card
    sdcs_set();

    // set the CACHE bank
    set_ram_bank(RAM_BANK_CACHE);

    clear_screen();
    terminal_init(3, 20);

    // set number of kb of memory
    // memory[0x605C] == 1 --> 16 KiB (0x6000 - 0x9FFF)
    //                   2 --> 32 KiB (0x6000 - 0xDFFF)
    //                   3 --> 40 KiB (0x6000 - 0xFFFF)
    const uint8_t nrkb = memory[0x605C] <= 2 ? memory[0x605C] * 16 : 40;

    sprintf(&vidmem[0x50], "%c%cSDCARD READER", TEXT_DOUBLE, COL_CYAN);
    sprintf(&vidmem[0x50*22], "Version: %s. Memory model: %i kb.", __VERSION__, nrkb);
    sprintf(&vidmem[0x50*23], "Compiled at: %s / %s", __DATE__, __TIME__);

    // initialize command line
    memset(__input, 0x00, INPUTLENGTH+1);
    memset(__lastinput, 0x00, INPUTLENGTH);

    // turn LEDs off
    z80_outp(PORT_LED_IO, 0x00);

    // mount sd card
    if(init_sdcard() != 0) {
        print_error("Cannot connect to SD-CARD.");
        for(;;){}
    }

    print_recall("Mounting partition 1..");
    uint32_t lba0 = read_mbr();
    if(lba0 == 0) {
        print_error("Cannot connect to SD-CARD.");
        for(;;){}
    } else {
        read_partition(lba0);
        print("Partition 1 mounted");
        print("System ready.");

        // insert cursor
        sprintf(termbuffer, "%c>%c", COL_CYAN, COL_WHITE);
        terminal_redoline();
    }
}

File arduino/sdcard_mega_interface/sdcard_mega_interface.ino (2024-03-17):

#include "fat32.h"

void setup() {
  init_sdcard();
}

uint8_t resp[6];    // use a 6 bit response buffer
uint8_t block[514]; // use 512 bytes for reading blocks + 2 bytes for the checksum

void loop() {
  // open the sd card interface
  access_sd();

  // read first sector
  open_command();
  cmd17(resp, 0x00000000);
  print_response("CMD17", resp, 1);
  read_block(block);
  close_command();
  //print_datablock(block);
  analyse_partitions(block);

  // obtain first sector of partition
  uint32_t lba_begin = get_lba_begin(block);
  open_command();
  cmd17(resp, lba_begin);
  print_response("CMD17", resp, 1);
  read_block(block);
  close_command();
  //print_datablock(block);
  FATData fatdata;
  analyse_first_sector_fat(block, &fatdata);
  print_fat32_data(&fatdata);

  while(1){} // set infinite loop
}

/**
 * Access the SD card
 * 
 * CMD0 > CMD8 > ACMD41 -> ready
 */
void access_sd() {
  cs_reset();

  /* 
   * first send 72 pulses to the SD card 
   */
  for(uint8_t i=0; i<12; i++) {
    write_byte(0xFF);  
  }

  open_command();
  cmd0(resp);
  print_response("CMD0", resp, 1);

  cmd8(resp);
  print_response("CMD8", resp, 5);

   /*
   * WRITE ACDM41
   */

  resp[0] = 5;
  uint8_t ctr = 0;
  while(resp[0] != 0) {
    ctr++;
    cmd55(resp);
    //print_response("CMD55", resp, 1);
    
    acmd41(resp);
    //print_response("ACMD41", resp, 1);
  
    delay(50);
  }
  Serial.print("Accepted ACMD41: ");
  Serial.print(ctr);
  Serial.println(" attempts.");

  cmd58(resp);
  print_response("CMD58", resp, 5);
  close_command();
}

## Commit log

2024-04-08 LEDs and improved SD card assembly rountines (#2)
    * Adding secondary LEDs
    * Fixing bug in erroneously triggered LEDs
    * Fixing bug in RAM/ROM leds
    * Update config.h
    * Adding LEDs in software and improvSD card assembly routines
    [p2000t-sdcard-top.stl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]
2024-04-09 Revising PCB
    [port2-sdcard-interface-B_Cu.gbr, port2-sdcard-interface-B_Mask.gbr, port2-sdcard-interface-B_Paste.gbr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]
2024-04-10 Improving cases
    [p2000t-sdcard-bottom.stl, p2000t-sdcard-top.stl]
2024-04-20 Improved external RAM copying routines (#3)
    * Showing partition volume name
    * Polishing internal RAM routines
    * Adding comments
    * Adding custom copy routines for SD-card to external RAM
    * Fixing Makefile adjustment
    [port2-sdcard-interface-B_Cu.gbr, port2-sdcard-interface-B_Mask.gbr, port2-sdcard-interface-B_Paste.gbr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]
2024-04-26 Adding 4mm inserts
    [p2000t-sdcard-top_4mm_inserts.stl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]
2024-04-27 Modifying case and changing flasher to also accept SST39SF020 SST39SF040 chips
    [p2000t-sdcard-bottom.stl, p2000t-sdcard-top_4mm_inserts.stl]
2024-04-27 Changing PCB to also accept SST39SF020 and SST39SF040 chips
    [port2-sdcard-interface-B_Cu.gbr, port2-sdcard-interface-B_Mask.gbr, port2-sdcard-interface-B_Paste.gbr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]
2024-05-01 Patch 0.4.0 (#5)
    * Initial commit retrieving CAS info
    * Adding byte replacement function
    * Refactoring C to assembly
    * Further refactoring SD-card routines
    * Further pruning functions and migrating SD card routines to assembly
    * Migrating SD card buffer to external RAM and fixing lscas command
    * Changing resistor value
    * Reintroducing LEDtest and hexdump
    * Expanding README
    * Adding badges
    [port2-sdcard-interface.kicad_pcb, port2-sdcard-interface.kicad_sch]
2024-05-10 Patch v0.6.0 (#7)
    * Adding memory model
    * Allowing execution of custom programs from SD card
    * Removing wrong files
    * Further pruning obsolete files
    * Replacing front images
    * Expanding README.md
    * Revising image
    * Allowing launching of external programs
    * Showing partition size and removing less relevant data
    * Fixing typos
    * Adding hexdumps for ROM, RAM and main memory
    * Expanding README.md
    * Adding CRC16 check for monitor and shuffling routines
    * Pruning map file
    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
    [port2-sdcard-interface.kicad_pcb, port2-sdcard-interface.kicad_sch]
2024-05-27 PCB revision 6 (#9)
    * Setting port addresses in header and include files
    * Updating rev and changing 0x60 to 0x40
    * Changing port for BASICmod
    * Incrementing version number
    * Adding enclosure files, changing CI and adding option to disable hardware test
    * Fixing CI
    * Adding README.md
    [p2000t-sdcard-bottom-arrow.stl, p2000t-sdcard-bottom-main.stl, p2000t-sdcard-bottom.3mf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]
2024-06-08 Creating separate SD-CARD test cartridge and modifying SD-card detection routine
    [port2-sdcard-interface.kicad_sch]
2024-06-29 Creation of multirom image (#10)
    * Creating 512k multirom image
    * Fixing suffixes
    * Splitting release upload
    * Removing incorrect dependency
    * Adding indent
    * Yet another attempt
    * Using BASH file
    * Fixing output file
    * Using Python for multirom image building
    * Adding card creation
    * Adjusting name
    * Fixing identation
    * Adding checkout
    [p2000t_multicartridge-bottom-osscillator-hole.stl]
2024-07-19 Patch v0.7.4 (#11)
    * Initial commit SD-card dumper
    * Adding help command
    * Revising README.md
    * Fixing bug in hex to uint16t conversion
    * Refactoring print functions
2024-07-21 Expanding documentation and showing PCB layout
2024-07-31 Version 0.8.0 (#13)
    * Initial commit diagnostics cartridge and fixing bug allowing for more diverse sd-cards.
    * Removing map file
    * Fix bug in reporting partition capactities
    * Finding file and folders in diag cartridge
    * Polishing output
    * Storing writetest
    * Moving folder
    * Adding explanation to test
    * Creating BOM/CPL for assembly service
    * ReOptimizing instructions
    * End of day commit
    * Timeout and data errors
    * Succesfully creating new file
    * Polishing FAT32 routines
    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
    [port2-sdcard-interface.kicad_sch, port2-sdcard-interface_bom_bot.csv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]
2024-08-02 Another attempt inserting the tag
2024-09-14 Miniboard (#15)
    * Preflight
    * Updating session
    * Finalizing rev0
    * Adding brackets
    * Small revision of miniboard and enabling autoboot function
    * Adding image
    [internal-sdcard-interface-B_Cu.gbr, internal-sdcard-interface-B_Mask.gbr, internal-sdcard-interface-B_Paste.gbr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]
2024-10-19 Increasing hole depth
    [p2000t-sdcard-bottom-main.stl]
2024-10-22 Fixing label
    [p2000t-sdcard-top-label01.stl]
2024-10-22 Tuning enclosure
    [p2000t-sdcard-bottom-main.stl, p2000t-sdcard-top-main.stl]
2024-12-10 Fixing value in schematic
    [port2-sdcard-interface.kicad_pcb, port2-sdcard-interface.kicad_sch]
2025-01-02 Removing copper pour around edge connector (#17)
    [port2-sdcard-interface-B_Cu.gbr, port2-sdcard-interface-B_Mask.gbr, port2-sdcard-interface-B_Paste.gbr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]
2025-01-06 Improving case
    [p2000t-sdcard-bottom-main.stl, p2000t-sdcard-bottom-namelabel.stl, p2000t-sdcard-top-main.stl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]

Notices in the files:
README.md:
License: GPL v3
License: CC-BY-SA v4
